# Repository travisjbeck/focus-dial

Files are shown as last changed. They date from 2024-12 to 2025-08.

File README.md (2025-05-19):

## The Story

I noticed that I am most productive when I set a timer to complete a task. This became even more apparent as I was learning to type again as there were drastically diminishing returns on learning after 25 minutes or so. 

So, I started looking for a "nice" timer to use. The nicer the better. I love beautiful objects and it seems like a super purposeful item like this is ripe for badass design and function. My initial search on amazon surfaced some decent cheap basic cheap options, and some very odd dated looking "pomodoro" specific timers. Nothing like I was looking for. I was looking for the "Peak Design" version of a workspace timer. Then, I found an indie gogo for exactly what I was looking for.   It had been funded in 48 hours and featured in Time Magazine, had tons of press, but sadly, they never shipped. Reading the company posts on indiegogo over time it became apparent these guys had a good idea, but no idea what they were doing. Even the product, upon closer inspection had some major flaws.  

Searching on, I came across a youtuber that was an original backer of the "Chi Timer" and wanted to see if he could just recreate it with readily available components and a 3D printer. He built something better in some ways, but lacking in others. He put the whole project on GitHub and created an instructable to walk people through building their own "Focus Timer". That video has been out 4 weeks and has 200,000 views. 

### The Spark

  It seems like there are a whole bunch of folks like me willing to shell out top dollar or spend many hours tinkering in order to have this product on their desks.  I get it.Its special. Its a beautiflu obnect that turns a mundane task into a ritual. rituals are powerful habit builders. People understand this. The best part is the mac and ios "Focus Mode" integrations as well as the unlimited integration potential of a custom webhook. 

  Let me see if I can build this and understand how it works. I want one, first of all, second of all, with some iteration this could be a commercially viable gadget that lots of people have already validated. I know this world. I know lots of people to make this happen. I've done it before and made a shit ton of invaluable mistakes that I don't have to make again. The intersection of software and hardware and design is the strongest gravitational pull I've ever felt in an idea. The challenge is real, and that's exciting. 

### The Expansion

Tariffs! Right, times have changed. Do I even want to make it in China? it's cheaper and easier, but is it exciting, does it help create the future I want? No.  We used to make things here. Great things. And thats important. Meaningful work and cratfmanship are important. The few proud people of America that get to work on meaningful, well-craftedh made-in-america things, be it jeans or pianos, they work hard and their work gives them meaning because they are working for something bigger than themselves or even the product. Can we make simple electronics in a plastic / wood / metal shell in America? of course. we can just do things. Ahh, but how much will it cost?  As much as it costs. Add the margin you need and sell it for top dollar. Just make sure as hell you deliver a "top-dollar" experience. Apple's not cornered the market on this making of beautiful objects and selling them for top dollar? Anyone can do that if they execute with the correct vision. I also think that just even "trying" to do this would win millions in free medea exposure. The timing is ripe. The mission becomes larger than the company or product.

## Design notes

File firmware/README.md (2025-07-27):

# Timer Arduino - Smooth Scrolling Demo

This is a high-performance smooth scrolling demo with three black screens for the ESP32-S3-Touch-AMOLED-1.75 device.

## Features
- Three scrollable screens with centered text
- Smooth horizontal scrolling with swipe gestures
- 16-bit RGB565 color (no color conversion)
- Optimized for 466x466 AMOLED display

## Hardware
- ESP32-S3-Touch-AMOLED-1.75 (WaveShare)
- QSPI display interface
- Capacitive touch

## Setup Instructions

1. **Copy Libraries**
   ```bash
   # From this directory, copy the required libraries:
   cp -r ../AMOLEDEXAMPLES/Arduino-v3.1.0/libraries/* ./libraries/
   ```

2. **Open in Arduino IDE**
   - Open `TheTimerArduino.ino` in Arduino IDE
   - Select Board: ESP32-S3 Dev Module
   - Select Port: /dev/cu.usbmodem2101 (or your device port)

3. **Configure Arduino IDE**
   - Board Settings:
     - Flash Size: 4MB
     - Partition Scheme: Default 4MB with spiffs
     - PSRAM: OPI PSRAM
     - Flash Mode: QIO 80MHz

4. **Upload**
   - Click Upload button in Arduino IDE
   - The device will show three scrollable black screens with text

## Troubleshooting
- If libraries are not found, ensure you've copied them from the AMOLEDEXAMPLES folder
- If touch doesn't work, check the I2C connections (SDA:15, SCL:14)
- If display doesn't work, verify QSPI connections match pin_config.h

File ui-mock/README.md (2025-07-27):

# Muji Japanese Minimal Timer UI - 466x466 Round Display

A minimalist timer interface inspired by Japanese design philosophy and Muji's aesthetic principles. Features warm, natural tones and embraces Ma (negative space).

## Design Principles

### Japanese Minimalism
- **Ma (間)**: Generous negative space throughout
- **Kanso (簡素)**: Essential elements only - no decorative buttons
- **Wabi-Sabi (侘寂)**: Natural, warm imperfections over sterile perfection

### Interface Design
- **No buttons**: Pure touch interaction, no pause/stop/start controls
- **Single accent color**: Muted sage green (#c2e189) throughout
- **Typography-focused**: Light weights with natural spacing
- **Automatic theme switching**: Demonstrates both modes seamlessly

## Structure

- `index.html` - Four screen layouts with Japanese minimal aesthetic
- `css/styles.css` - Warm, natural color palette with AMOLED-optimized dark mode
- `theme_info.md` - Detailed explanation of Japanese design philosophy
- Each display is 466x466px with circular boundary

## Color Palette

### Light Mode - Natural Paper Tones
```css
var(--light-bg-primary)     /* #FAFAF8 - Warm off-white */
var(--light-bg-secondary)   /* #F5F4F0 - Subtle warm gray */
var(--light-text-primary)   /* #57544F - Deep charcoal */
var(--light-text-secondary) /* #A8A5A0 - Soft warm gray */
var(--light-accent)         /* #c2e189 - Muted sage green */
var(--light-border)         /* #E8E6E1 - Subtle warm border */
```

### Dark Mode - AMOLED Optimized
```css
var(--dark-bg-primary)      /* #000000 - Pure black */
var(--dark-bg-secondary)    /* #0A0A0A - Near black */
var(--dark-text-primary)    /* #F5F4F0 - Warm off-white */
var(--dark-text-secondary)  /* #B8B5B0 - Muted warm gray */
var(--dark-accent)          /* #c2e189 - Same sage green */
var(--dark-border)          /* #1A1A1A - Subtle border */
```

## Screen Designs

### 1. Idle Screen
- **Central time display** (14:32) with ultra-light typography
- **Subtle status message** "No active timers"
- **Maximum Ma (negative space)** for peaceful rest state

### 2. Project Selection  
- **Clean vertical list** with perfect rhythm
- **Active selection** highlighted with sage green accent
- **Natural spacing** between project names

### 3. Timer Running
- **Large countdown display** as hero element
- **Minimal progress ring** (single pixel stroke)
- **Small project context** label above

### 4. Duration Selection
- **Prominent time selection** display
- **Text-only preset buttons** in horizontal layout
- **Active state** shown through color and subtle underline

## Typography Hierarchy

### Weight-Based Hierarchy
- **Ultra-light (200)**: Large time displays for maximum readability
- **Light (300)**: Body text and supporting information
- **Regular (400)**: Active states and emphasis only

### Size Scale
- **72px-96px**: Primary time displays
- **16px-18px**: Comfortable body text
- **14px**: Supporting labels and context

## Implementation Features

- **No interactive buttons**: Embraces pure touch/rotary navigation
- **Automatic theme demonstration**: Switches every 5 seconds
- **Responsive scaling**: Maintains proportions across screen sizes
- **AMOLED optimization**: Pure black backgrounds in dark mode
- **Natural transitions**: Soft, organic animation timing

## Design Philosophy

See `theme_info.md` for detailed explanation of Japanese design principles including Ma (negative space), Wabi-Sabi (imperfect beauty), and Kanso (simplicity).

## File Structure

```
ui_samples_v3_2/
├── index.html          # Four screen implementations
├── css/
│   └── styles.css      # Japanese minimal theme styles
├── theme_info.md       # Design philosophy documentation
└── README.md           # This file
```

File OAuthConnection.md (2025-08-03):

# thetimer.app OAuth Integration Implementation Guide

## Overview

This document outlines the implementation of OAuth-style authentication between the Timer Device and thetimer.app, allowing seamless connection without manual API key entry.

## Architecture

### Components

1. **Timer Device (Client)**
   - Web interface at `http://thetimer.local`
   - Runs on ESP32-S3 with web server
   - Stores API credentials in NVS

2. **thetimer.app (Server)**
   - Next.js application
   - Handles user authentication
   - Generates device-specific API keys

### Authentication Flow

```
Timer Device                    thetimer.app                    User
     |                              |                             |
     |--- 1. Click "Connect" ------>|                             |
     |                              |                             |
     |<-- 2. Open popup window -----|                             |
     |    (to /device-auth)         |                             |
     |                              |<---- 3. User logs in -------|
     |                              |                             |
     |                              |---- 4. Generate API key --->|
     |                              |                             |
     |<-- 5. postMessage with ------|                             |
     |    credentials               |                             |
     |                              |                             |
     |--- 6. Save credentials ----->|                             |
     |                              |                             |
     |<-- 7. Confirm connection ----|                             |
```

## Implementation Details

### Timer Device Side (Web Interface)

#### 1. Update UI in `firmware/data/index.html`

Replace the current webhook configuration section with:

```html
<section class="card" id="integration-section">
  <div class="card-header">
    <h2>
      <i data-lucide="cloud" class="icon"></i>
      thetimer.app Integration
    </h2>
  </div>
  <div class="form-content">
    <!-- Not Connected State -->
    <div id="not-connected" class="connection-state">
      <div class="integration-info">
        <p>Connect to thetimer.app to:</p>
        <ul>
          <li>Sync your timer data to the cloud</li>
          <li>Access detailed analytics and reports</li>
          <li>Share projects with your team</li>
          <li>7-day free trial, then subscription required</li>
        </ul>
      </div>
      <button type="button" class="btn primary-btn" id="connect-button">
        <i data-lucide="link" class="icon"></i>
        <span>Connect to thetimer.app</span>
      </button>
    </div>
    
    <!-- Connected State -->
    <div id="connected" class="connection-state" style="display: none;">
      <div class="connection-status">
        
        <div class="status-info">
          <p class="status-text">Connected to thetimer.app</p>
          
          <p class="last-sync">Last synced: <span id="last-sync-time">Never</span></p>
        </div>
      </div>
      <button type="button" class="btn secondary-btn danger-btn" id="disconnect-button">
        <i data-lucide="unlink" class="icon"></i>
        <span>Disconnect</span>
      </button>
    </div>
  </div>
</section>
```

#### 2. JavaScript OAuth Handler in `firmware/data/app.js`

```javascript
// OAuth Configuration
const TIMER_APP_URL = 'https://thetimer.app';
const DEVICE_AUTH_ENDPOINT = '/device-auth';
const WEBHOOK_ENDPOINT = '/api/webhook';

let authWindow = null;

// Initialize connection state
async function initializeIntegration() {
  const apiKey = await fetchStoredApiKey();
  updateConnectionUI(!!apiKey);
  
  if (apiKey) {
    // Verify connection is still valid
    verifyConnection(apiKey);
  }
}

// Handle Connect button click
document.getElementById('connect-button').addEventListener('click', async () => {
  // Generate state parameter for security
  const state = generateRandomState();
  sessionStorage.setItem('oauth_state', state);
  
  // Get device information
  const deviceInfo = await getDeviceInfo();
  
  // Build OAuth URL
  const authUrl = new URL(DEVICE_AUTH_ENDPOINT, TIMER_APP_URL);
  authUrl.searchParams.append('device_id', deviceInfo.id);
  authUrl.searchParams.append('device_name', deviceInfo.name);
  authUrl.searchParams.append('state', state);
  authUrl.searchParams.append('callback_origin', window.location.origin);
  
  // Open popup window
  const width = 600;
  const height = 700;
  const left = (window.screen.width - width) / 2;
  const top = (window.screen.height - height) / 2;
  
  authWindow = window.open(
    authUrl.toString(),
    'TimerAppAuth',
    `width=${width},height=${height},left=${left},top=${top},toolbar=no,menubar=no`
  );
  
  // Start listening for response
  window.addEventListener('message', handleAuthMessage);
});

// Handle postMessage from thetimer.app
async function handleAuthMessage(event) {
  // Verify origin
  if (event.origin !== TIMER_APP_URL) return;
  
  // Verify state
  const savedState = sessionStorage.getItem('oauth_state');
  if (!savedState || event.data.state !== savedState) {
    console.error('Invalid state parameter');
    return;
  }
  
  // Extract credentials
  const { api_key, account_email, webhook_url } = event.data;
  
  if (api_key) {
    // Save credentials
    await saveCredentials({
      api_key,
      webhook_url: webhook_url || `${TIMER_APP_URL}${WEBHOOK_ENDPOINT}`,
      account_email
    });
    
    // Update UI
    updateConnectionUI(true, account_email);
    
    // Close popup
    if (authWindow) {
      authWindow.close();
    }
    
    // Clean up
    sessionStorage.removeItem('oauth_state');
    window.removeEventListener('message', handleAuthMessage);
    
    showMessage('Successfully connected to thetimer.app!', 'success');
  }
}

// Save credentials to device
async function saveCredentials(credentials) {
  const response = await fetch('/api/webhook', {
    method: 'POST',
    headers: { 'Content-Type': 'application/json' },
    body: JSON.stringify({
      webhook_url: credentials.webhook_url,
      api_key: credentials.api_key
    })
  });
  
  if (!response.ok) {
    throw new Error('Failed to save credentials');
  }
  
  // Store additional metadata locally
  localStorage.setItem('timer_app_email', credentials.account_email);
  localStorage.setItem('timer_app_connected_at', new Date().toISOString());
}

// Handle disconnect
document.getElementById('disconnect-button').addEventListener('click', async () => {
  if (confirm('Are you sure you want to disconnect from thetimer.app?')) {
    await fetch('/api/webhook', {
      method: 'POST',
      headers: { 'Content-Type': 'application/json' },
      body: JSON.stringify({
        webhook_url: '',
        api_key: ''
      })
    });
    
    localStorage.removeItem('timer_app_email');
    localStorage.removeItem('timer_app_connected_at');
    
    updateConnectionUI(false);
    showMessage('Disconnected from thetimer.app', 'success');
  }
});

// Utility functions
function generateRandomState() {
  return Array.from(crypto.getRandomValues(new Uint8Array(16)))
    .map(b => b.toString(16).padStart(2, '0'))
    .join('');
}

async function getDeviceInfo() {
  // Get device MAC address as unique ID
  const response = await fetch('/api/system/info');
  const info = await response.json();
  
  return {
    id: info.mac_address || 'unknown',
    name: info.hostname || 'Timer Device'
  };
}

function updateConnectionUI(isConnected, email = null) {
  const notConnected = document.getElementById('not-connected');
  const connected = document.getElementById('connected');
  
  if (isConnected) {
    notConnected.style.display = 'none';
    connected.style.display = 'block';
    
    if (email) {
      document.getElementById('account-email').textContent = email;
    } else {
      const savedEmail = localStorage.getItem('timer_app_email');
      if (savedEmail) {
        document.getElementById('account-email').textContent = savedEmail;
      }
    }
    
    // Update last sync time
    updateLastSyncTime();
  } else {
    notConnected.style.display = 'block';
    connected.style.display = 'none';
  }
}
```

### thetimer.app Side (Next.js)

#### 1. Device Authentication Page (`pages/device-auth.tsx`)

```typescript
import { useEffect, useState } from 'react';
import { useRouter } from 'next/router';
import { useSession } from 'next-auth/react';

export default function DeviceAuth() {
  const router = useRouter();
  const { data: session, status } = useSession();
  const [isProcessing, setIsProcessing] = useState(false);
  
  const { device_id, device_name, state, callback_origin } = router.query;

  useEffect(() => {
    // Redirect to login if not authenticated
    if (status === 'unauthenticated') {
      router.push(`/auth/signin?callbackUrl=${encodeURIComponent(router.asPath)}`);
    }
  }, [status, router]);

  useEffect(() => {
    // Process authentication once logged in
    if (session && device_id && state && callback_origin && !isProcessing) {
      handleDeviceAuth();
    }
  }, [session, device_id, state, callback_origin]);

  const handleDeviceAuth = async () => {
    setIsProcessing(true);
    
    try {
      // Create or retrieve API key for this device
      const response = await fetch('/api/devices/authenticate', {
        method: 'POST',
        headers: { 'Content-Type': 'application/json' },
        body: JSON.stringify({
          device_id,
          device_name,
          user_id: session.user.id
        })
      });
      
      const data = await response.json();
      
      if (data.api_key) {
        // Send credentials back to device
        window.opener.postMessage({
          api_key: data.api_key,
          webhook_url: `${process.env.NEXT_PUBLIC_APP_URL}/api/webhook`,
          account_email: session.user.email,
          state
        }, callback_origin as string);
        
        // Show success and close window
        setTimeout(() => {
          window.close();
        }, 1000);
      }
    } catch (error) {
      console.error('Device authentication failed:', error);
      // Show error to user
    }
  };

  return (
    <div className="min-h-screen flex items-center justify-center">
      <div className="max-w-md w-full space-y-8 p-8">
        <div className="text-center">
          <h2 className="text-3xl font-bold">Connect Your Timer Device</h2>
          {session ? (
            <>
              <p className="mt-2 text-gray-600">
                Connecting device to your account: {session.user.email}
              </p>
              <div className="mt-4">
                
              </div>
            </>
          ) : (
            <p className="mt-2 text-gray-600">
              Please log in to connect your device
            </p>
          )}
        </div>
      </div>
    </div>
  );
}
```

#### 2. API Endpoint (`pages/api/devices/authenticate.ts`)

```typescript
import { NextApiRequest, NextApiResponse } from 'next';
import { getSession } from 'next-auth/react';
import { prisma } from '@/lib/prisma';
import { generateApiKey } from '@/lib/auth';

export default async function handler(req: NextApiRequest, res: NextApiResponse) {
  if (req.method !== 'POST') {
    return res.status(405).json({ error: 'Method not allowed' });
  }

  const session = await getSession({ req });
  if (!session) {
    return res.status(401).json({ error: 'Unauthorized' });
  }

  const { device_id, device_name } = req.body;

  try {
    // Check if device already exists
    let device = await prisma.device.findUnique({
      where: { device_id }
    });

    if (device && device.user_id !== session.user.id) {
      return res.status(403).json({ error: 'Device registered to another user' });
    }

    // Generate new API key
    const api_key = generateApiKey();

    if (device) {
      // Update existing device
      device = await prisma.device.update({
        where: { device_id },
        data: {
          api_key,
          last_connected: new Date()
        }
      });
    } else {
      // Create new device
      device = await prisma.device.create({
        data: {
          device_id,
          device_name,
          api_key,
          user_id: session.user.id,
          trial_ends_at: new Date(Date.now() + 7 * 24 * 60 * 60 * 1000) // 7 days
        }
      });
    }

    return res.status(200).json({
      api_key,
      device_id: device.device_id
    });
  } catch (error) {
    console.error('Device authentication error:', error);
    return res.status(500).json({ error: 'Internal server error' });
  }
}
```

## Security Considerations

1. **State Parameter**: Prevents CSRF attacks
2. **Origin Verification**: Only accept postMessage from thetimer.app
3. **HTTPS Required**: All communication over secure channels
4. **API Key Rotation**: Implement key rotation mechanism
5. **Device Binding**: API keys tied to specific device IDs

## Implementation Checklist

### Timer Device
- [ ] Update HTML with new integration UI
- [ ] Implement OAuth JavaScript handler
- [ ] Add connection state management
- [ ] Update CSS for connection status indicators
- [ ] Test popup window communication
- [ ] Handle error states gracefully

### thetimer.app
- [ ] Create device authentication page
- [ ] Implement device registration API
- [ ] Add device management to user dashboard
- [ ] Set up trial/subscription validation
- [ ] Configure CORS for device communication
- [ ] Test postMessage flow

## Testing

1. **Happy Path**
   - User clicks connect
   - Logs in successfully
   - Device receives credentials
   - Connection status updates

2. **Error Cases**
   - User closes popup without authenticating
   - Network failure during authentication
   - Invalid credentials
   - Expired trial

3. **Security**
   - Verify state parameter validation
   - Test origin verification
   - Ensure API keys are stored securely

## Future Enhancements

1. **Device Management Dashboard**: Allow users to see all connected devices
2. **Automatic Reconnection**: Handle token refresh
3. **Offline Queue**: Store timer data locally when disconnected
4. **Multi-device Sync**: Sync projects across devices
5. **Push Notifications**: Real-time updates to devices

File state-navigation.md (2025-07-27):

# Timer State Machine Navigation

## State Diagram

```
┌─────────────────┐
│   StartupState  │ (2 sec splash)
└────────┬────────┘
         │
         ▼
┌─────────────────┐
│ ProvisionState  │ (First run only - WiFi setup)
└────────┬────────┘
         │ WiFi configured
         ▼
┌─────────────────┐ Rotate Encoder  ┌─────────────────┐
│                 │ ───────────────> │                 │
│   IdleState     │                  │  AdjustState    │
│   (25:00)       │ <─────────────── │ (Timer Duration)│
│                 │    Tap Screen    │                 │
└────────┬────────┘                  └─────────────────┘
         │ Tap Screen
         ▼
┌─────────────────┐
│ProjectSelectState│ 
│ (Choose Project) │
└────────┬────────┘
         │ Tap Screen (Start Timer)
         ▼
┌─────────────────┐ Tap Screen      ┌─────────────────┐
│                 │ ───────────────> │                 │
│   TimerState    │                  │  PausedState    │
│   (Running)     │ <─────────────── │   (Paused)      │
│                 │    Tap Screen    │                 │
└────────┬────────┘                  └────────┬────────┘
         │ Long Press                         │ Long Press
         ▼                                    ▼
┌─────────────────┐
│   DoneState     │
│  (Completed)    │
└────────┬────────┘
         │ Tap Screen
         ▼
    [Back to IdleState]
```

## Input Summary

### Rotary Encoder
- **IdleState**: Rotate to enter AdjustState (timer duration)
- **AdjustState**: Rotate to change timer duration (5-240 min)
- **ProjectSelectState**: Rotate to scroll through projects

### Screen Tap
- **IdleState**: Tap to enter ProjectSelectState
- **AdjustState**: Tap to save duration and return to IdleState
- **ProjectSelectState**: Tap to select project and start timer
- **TimerState**: Tap to pause
- **PausedState**: Tap to resume
- **DoneState**: Tap to return to IdleState

### Long Press
- **TimerState**: Long press to end timer early
- **PausedState**: Long press to end timer early

### Power Button (Hardware)
- **Any State**: Press to enter deep sleep
- **Deep Sleep**: Press BOOT button to wake

### Inactivity
- **IdleState**: 3 minutes → Light sleep (touch to wake)
- **Other States**: No timeout during active use

## Key Behaviors

1. **WiFi Check**: On every boot, check if WiFi is configured. Skip ProvisionState if already set up.

2. **Timer Modes**: Timer can count up or down (need to clarify which mode is used when).

3. **Project Colors**: Each project has an associated color that affects:
   - LED ring color during timer
   - UI accent colors
   - Progress indicators

4. **State Persistence**: 
   - Timer duration saved between sessions
   - Current project remembered
   - WiFi credentials stored in NVS

5. **Simplified Input**: Everything is either:
   - Single tap (most common - state transitions)
   - Long press (only in timer/paused states to end timer)
   - Encoder rotation (value adjustments)

## Implementation Notes

1. **Touch Debouncing**: Already implemented in TheTimerArduino
2. **State Transition Animation**: Fade transitions already working
3. **Encoder Interrupts**: Need to implement on GPIO 17/18
4. **Long Press Detection**: Need to add to LVGL event handling
5. **WiFi Check**: Need to port from old firmware's NetworkController

## Testing Each Transition

1. Boot → Provision → Idle (first run)
2. Boot → Idle (subsequent runs)
3. Idle ↔ Adjust (encoder/tap cycle)
4. Idle → Project → Timer (tap flow)
5. Timer ↔ Paused (tap toggle)
6. Timer/Paused → Done (long press)
7. Done → Idle (tap)
8. Any → Sleep → Wake (power/inactivity)

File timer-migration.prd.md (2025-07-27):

# Timer Migration PRD - ESP32-S3-Touch-AMOLED-1.75

## Executive Summary

This document outlines the product requirements for migrating an existing timer application from ESP32 XIAO hardware with OLED display to the new ESP32-S3-Touch-AMOLED-1.75 hardware. The migration will preserve all existing functionality while leveraging the new hardware's superior display capabilities, touch interface, and power management features.

**Core Development Philosophy: Test Constantly, Build Consistently, Iterate in Small Chunks**

## Development Methodology

### Continuous Testing & Iteration

1. **Micro-Iterations**
   - Each feature implemented in small chunks
   - Compile and test after EVERY code change
   - Never accumulate untested changes
   - Roll back immediately if build fails

2. **Build-First Approach**
   ```bash
   # Standard build & test cycle (run after EVERY change)
   cd /Users/Travis/Developer/waveshare_hardware_test/TheTimerArduino && \
   arduino-cli compile --fqbn esp32:esp32:esp32s3:USBMode=hwcdc --build-property "build.psram_type=opi" && \
   arduino-cli upload -p /dev/cu.usbmodem32301 --fqbn esp32:esp32:esp32s3:USBMode=hwcdc && \
   sleep 2 && \
   esptool.py --port /dev/cu.usbmodem32301 read_mac >/dev/null 2>&1 && \
   sleep 0.5 && \
   timeout 30 cat /dev/cu.usbmodem32301
   ```

3. **Error-First Development**
   - Expect errors and plan for them
   - Add serial debugging before functionality
   - Test edge cases before happy path
   - Document every error and solution

4. **Incremental Feature Addition**
   - Start with minimal viable feature
   - Test thoroughly
   - Add one small enhancement
   - Test again
   - Repeat

## Hardware Specifications

### New Hardware: ESP32-S3-Touch-AMOLED-1.75
- **Display**: 466x466 AMOLED with 16-bit RGB565 color
- **Touch**: Capacitive touch screen (CSTXXX driver)
- **MCU**: ESP32-S3 with 8MB PSRAM
- **Interface**: QSPI (4-wire SPI) for display
- **Power**: AXP2101 PMU with battery management
- **RTC**: Built-in real-time clock controller
- **Connectivity**: WiFi, Bluetooth
- **Expansion**: TCA9554 IO expander for additional GPIO

### Peripheral Connections

#### Breakout Board Header (8-pin)
The ESP32-S3-Touch-AMOLED-1.75 provides an 8-pin header with:
- **IO18**: GPIO18
- **IO17**: GPIO17  
- **IO16**: GPIO16
- **RXD**: UART RX (can be used as GPIO)
- **TXD**: UART TX (can be used as GPIO)
- **3V3**: 3.3V power supply
- **GND**: Ground
- **VBUS**: 5V from USB

#### Rotary Encoder Connections
- **Encoder A**: IO17 (GPIO17)
- **Encoder B**: IO18 (GPIO18)
- **Encoder Common**: GND
- **Note**: The old firmware used GPIO43/8. Code will need to be updated for GPIO17/18.

#### NeoPixel LED Ring Connections
- **Data Pin**: IO16 (GPIO16)
- **Power**: 3V3 (for consistent 3.3V operation)
- **Ground**: GND
- **LED Count**: 24 LEDs (upgraded from 16)
- **Type**: NEO_GRB + NEO_KHZ800
- **Note**: Using 3.3V ensures consistent brightness whether on USB or battery power.

### Testing Points for Hardware
1. **GPIO Availability Test**: Verify each pin works before wiring
2. **Voltage Test**: Confirm 3.3V on all peripherals
3. **Current Draw Test**: Measure with all LEDs on
4. **Signal Integrity Test**: Check encoder pulses with scope

## Current Implementation Status

### Already Completed in TheTimerArduino
- ✅ Display initialized (466x466 AMOLED with Arduino_CO5300)
- ✅ Touch input working (CSTXXX driver)
- ✅ LVGL configured with proper buffers
- ✅ First UI screen complete (idle timer display)
- ✅ Custom fonts loaded (Roboto Mono 120pt, Barlow 24pt)
- ✅ Screen transitions with fade animation
- ✅ Tap navigation between screens
- ✅ Inactivity timeout (3 minutes → light sleep)
- ✅ Power button → deep sleep
- ✅ BOOT button → wake from deep sleep
- ✅ Touch wake from light sleep

### Hardware Setup
- **Physical Rotary Encoder**: Will connect to GPIO 17/18
- **NeoPixel LED Ring**: Will connect to GPIO 16
- **Touch Input**: Replaces all button functions with simple tap

## Migration Strategy

### Key Differences from Original Plan
1. **Physical Encoder Retained**: No virtual dial needed - using real rotary encoder
2. **Simplified Touch**: Primarily single tap, with long-press only in timer states to end timer
3. **Starting Point**: Display, touch, and sleep already working in TheTimerArduino
4. **UI Foundation**: First screen (idle timer) already implemented with custom fonts

### Input Mapping
- **Screen Tap** = Old button click (context-sensitive per state)
- **Long Press** = End timer early (only in TimerState and PausedState)
- **Encoder Rotation** = Value adjustment (unchanged)
- **Power Button** = Deep sleep (already implemented)
- **Touch Wake** = Wake from light sleep (already implemented)

### State Machine Navigation Flow

**Initial Boot**:
1. **StartupState** (2 seconds splash) → 
2. **ProvisionState** (if no WiFi configured) → Enter WiFi credentials
3. Skip to **IdleState** if WiFi already configured

**From IdleState** (main screen showing 25:00):
- **Rotate Encoder** → **AdjustState** (timer duration setting)
- **Tap Screen** → **ProjectSelectState**

**From AdjustState** (timer duration setting):
- **Rotate Encoder** → Adjust timer duration (5-240 minutes)
- **Tap Screen** → Save duration and return to **IdleState**

**From ProjectSelectState**:
- **Rotate Encoder** → Scroll through projects
- **Tap Screen** → Start timer → **TimerState**

**From TimerState** (timer running):
- **Tap Screen** → **PausedState**
- **Long Press** → End timer → **DoneState**

**From PausedState**:
- **Tap Screen** → Resume → **TimerState**
- **Long Press** → End timer → **DoneState**

**From DoneState**:
- **Tap Screen** → Return to **IdleState**

## Core Features to Migrate

### Implementation Order (Test-Driven)

#### Phase 1: State Machine Integration
**Port State Machine Framework**
- [ ] Copy state machine files from old firmware
- [ ] Update CMakeLists.txt / includes
- [ ] Create empty state implementations
- [ ] Test state transitions work
- [ ] Connect screen tap to state changes

**Integrate with Existing UI**
- [ ] Connect idle screen to IdleState
- [ ] Update timer display from state
- [ ] Test tap starts/stops timer
- [ ] Verify state persistence

#### Phase 2: Hardware Peripherals
**Physical Encoder Integration**
- [ ] Wire encoder to GPIO 17/18
- [ ] Test encoder rotation detection
- [ ] Port InputController with new pins
- [ ] Test value adjustment in AdjustState
- [ ] Verify interrupt handling works

**NeoPixel LED Ring**
- [ ] Wire LEDs to GPIO 16 with 3.3V power
- [ ] Test single LED at 3.3V
- [ ] Port LEDController to new pin
- [ ] Test all animation patterns
- [ ] Verify brightness levels adequate

#### Phase 3: State Implementation
**Core States**
- [ ] IdleState (with all tests)
- [ ] AdjustState (with all tests)
- [ ] TimerState (with all tests)
- [ ] ProjectSelectState (with all tests)
- [ ] PausedState & DoneState
- [ ] SleepState & power management
- [ ] Integration testing

#### Phase 4: Network Features
**WiFi Provisioning**
- [ ] Test 1: AP mode starts
- [ ] Test 2: Can connect to AP
- [ ] Test 3: Provisioning saves credentials
- [ ] Feature: WiFi provisioning works

**Web Server**
- [ ] Test 1: Server starts
- [ ] Test 2: Index page loads
- [ ] Test 3: API responds
- [ ] Feature: Basic web interface

**Project Management**
- [ ] Test 1: Create project via API
- [ ] Test 2: List projects
- [ ] Test 3: Delete project
- [ ] Test 4: Projects persist
- [ ] Feature: Full project CRUD

### Testing Infrastructure

#### Serial Debug Framework
```cpp
// Add to every state enter()
USBSerial.println("=== ENTERING STATE: StateName ===");
USBSerial.print("Free heap: ");
USBSerial.println(ESP.getFreeHeap());
USBSerial.print("Timestamp: ");
USBSerial.println(millis());

// Add to every state exit()
USBSerial.println("=== EXITING STATE: StateName ===");
```

#### Memory Monitoring
```cpp
// Run every 10 seconds in loop()
static unsigned long lastMemCheck = 0;
if (millis() - lastMemCheck > 10000) {
    USBSerial.print("HEAP: ");
    USBSerial.print(ESP.getFreeHeap());
    USBSerial.print(" PSRAM: ");
    USBSerial.println(ESP.getFreePsram());
    lastMemCheck = millis();
}
```

#### Crash Recovery
```cpp
// Add to setup()
esp_reset_reason_t reset_reason = esp_reset_reason();
USBSerial.print("Reset reason: ");
USBSerial.println(reset_reason);
if (reset_reason == ESP_RST_PANIC) {
    USBSerial.println("RECOVERED FROM CRASH!");
    // Log crash context if available
}
```

### Error Handling Strategy

1. **Never Silent Fail**
   - Every function returns success/failure
   - Every failure logs detailed error
   - Every error has recovery path

2. **Defensive Programming**
   ```cpp
   // Example pattern for all functions
   bool initializeComponent() {
       USBSerial.println("Initializing component X...");
       
       if (!component.begin()) {
           USBSerial.println("ERROR: Component X failed to initialize");
           USBSerial.println("Attempting recovery...");
           delay(100);
           if (!component.begin()) {
               USBSerial.println("FATAL: Component X unrecoverable");
               return false;
           }
       }
       
       USBSerial.println("Component X initialized successfully");
       return true;
   }
   ```

3. **Test Harness Mode**
   ```cpp
   // Add compile flag for test mode
   #ifdef TEST_MODE
   void runTestSuite() {
       testDisplay();
       testTouch();
       testEncoder();
       testLEDs();
       testStates();
       testMemory();
       reportResults();
   }
   #endif
   ```

## UI/UX Requirements

### Iterative UI Development

1. **Phase 1: Boxes and Text**
   - Just get text on screen
   - Verify positioning
   - Test touch zones

2. **Phase 2: Fonts and Sizes**
   - Add custom fonts one at a time
   - Test memory impact
   - Verify readability

3. **Phase 3: Colors and Polish**
   - Add colors incrementally
   - Test brightness levels
   - Verify power consumption

4. **Phase 4: Animations**
   - Start with simple fades
   - Test performance impact
   - Add complexity gradually

### Screen Layouts (Based on TheTimerUI.png)

#### Testing Each Screen
1. **Create static mockup first**
2. **Test touch zones with colored boxes**
3. **Add real content**
4. **Test state persistence**
5. **Test transitions in/out**

## Technical Requirements

### Build Configuration
```bash
# Always use these exact flags
--fqbn esp32:esp32:esp32s3:USBMode=hwcdc
--build-property "build.psram_type=opi"
```

### Critical Testing Points

1. **Display Buffer Allocation**
   - Test with small buffer first
   - Increase size gradually
   - Monitor free memory
   - Find optimal size

2. **Touch Calibration**
   - Log raw coordinates
   - Test all four corners
   - Verify center point
   - Check edge detection

3. **Power Management**
   - Test wake sources individually
   - Measure current in each state
   - Verify sleep entry/exit
   - Test battery life

## Continuous Integration

### Testing Checklist
- [ ] Each feature: Build and upload
- [ ] After implementation: Test all states
- [ ] Regular intervals: Memory leak check
- [ ] Each error: Document and fix immediately

### Error Log Template
```
Error: [Description]
Context: [What was being tested]
Serial Output: [Paste output]
Solution: [How it was fixed]
Prevention: [How to avoid in future]
```

## Acceptance Criteria

### Incremental Acceptance
Each feature must pass these gates:

1. **Gate 1: Builds without warnings**
2. **Gate 2: Uploads successfully**
3. **Gate 3: Runs for 1 minute without crash**
4. **Gate 4: Survives 10 state transitions**
5. **Gate 5: Works after power cycle**
6. **Gate 6: Memory usage stable**

### Feature-Specific Tests
Document specific test cases for each feature BEFORE implementing.

## Risk Mitigation

### Common Pitfalls & Solutions

1. **Memory Fragmentation**
   - Test: Long-running state transitions
   - Solution: Pre-allocate all buffers
   - Prevention: No dynamic allocation in loop()

2. **I2C Conflicts**
   - Test: Access all I2C devices sequentially
   - Solution: Add mutexes if needed
   - Prevention: Single I2C manager class

3. **Display Corruption**
   - Test: Rapid screen switches
   - Solution: Proper LVGL mutex usage
   - Prevention: Single display update point

4. **Touch Glitches**
   - Test: Rapid touch events
   - Solution: Debouncing and rate limiting
   - Prevention: State-based touch handling

## Development Tools

### Essential Debugging Commands
```bash
# Monitor with timestamp
arduino-cli monitor -p /dev/cu.usbmodem32301 --timestamp

# Quick reset and monitor
esptool.py --port /dev/cu.usbmodem32301 read_mac && sleep 0.5 && cat /dev/cu.usbmodem32301

# Flash and monitor in one command
./build_and_monitor.sh
```

### Performance Monitoring
```cpp
// Add to critical sections
unsigned long start = micros();
// ... code to measure ...
unsigned long duration = micros() - start;
if (duration > 1000) { // Log if > 1ms
    USBSerial.print("PERF WARNING: ");
    USBSerial.print(functionName);
    USBSerial.print(" took ");
    USBSerial.print(duration);
    USBSerial.println("us");
}
```

## Migration Challenges & Solutions

### 1. Physical Encoder Pin Changes
**Challenge**: Old pins GPIO 43/8 don't exist on new hardware
**Solution**: Remap to GPIO 17/18 on breakout header
```cpp
#define ENCODER_A_PIN 17  // Was 43
#define ENCODER_B_PIN 18  // Was 8
```

### 2. Long Press Detection
**Challenge**: Need long press for ending timer early
**Solution**: Add LVGL long press events
```cpp
lv_obj_add_event_cb(screen, long_press_cb, LV_EVENT_LONG_PRESSED, NULL);
lv_obj_add_event_cb(screen, long_press_repeat_cb, LV_EVENT_LONG_PRESSED_REPEAT, NULL);
```

### 3. NeoPixel 3.3V Operation
**Challenge**: LEDs designed for 5V, using 3.3V supply
**Solution**: 
- Test signal integrity first
- Reduce brightness if needed
- Most WS2812B work fine at 3.3V

### 4. Display Memory Requirements
**Challenge**: 466x466 display needs large buffers
**Solution**: Already using PSRAM in TheTimerArduino
```cpp
buf1 = (lv_color_t*)heap_caps_malloc(buffer_size * sizeof(lv_color_t), 
                                      MALLOC_CAP_DMA | MALLOC_CAP_SPIRAM);
```

### 5. Touch Wake Configuration
**Challenge**: Different wake source than physical button
**Solution**: Already implemented using GPIO11
```cpp
gpio_wakeup_enable(GPIO_NUM_11, GPIO_INTR_LOW_LEVEL);
esp_sleep_enable_gpio_wakeup();
```

### 6. State Machine Integration
**Challenge**: Connect existing UI to state logic
**Solution**: 
- Port state files from old firmware
- Map touch/encoder events to state handlers
- Preserve existing screen transition code

### 7. WiFi Provisioning Check
**Challenge**: Skip provisioning if already configured
**Solution**: Check NVS on boot
```cpp
if (!networkController.isWiFiProvisioned()) {
    stateMachine.changeState(&provisionState);
} else {
    stateMachine.changeState(&idleState);
}
```

### 8. Project Color Preview
**Challenge**: Show colors on both display and LEDs
**Solution**: Update display preview while keeping LED feedback

## Testing Strategy

### Hardware Test Order
1. Encoder on new pins (GPIO 17/18)
2. NeoPixels at 3.3V (GPIO 16)
3. Combined encoder + LED operation
4. State transitions with real hardware

### Debug Infrastructure
```cpp
#define DEBUG_MIGRATION 1
#if DEBUG_MIGRATION
  #define MIG_LOG(x) USBSerial.println(x)
#else
  #define MIG_LOG(x)
#endif
```

## Success Metrics

1. **Build Success Rate**: >95% (track daily)
2. **Crash-Free Runtime**: >4 hours continuous
3. **Memory Stability**: <5% variation over 1 hour
4. **Response Time**: <100ms for all interactions
5. **Code Coverage**: Test every state transition

## Appendix: Pin Assignments Summary

| Function | GPIO Pin | Header Pin | Notes |
|---|---|---|---|
| LED Data | GPIO16 | IO16 | NeoPixel data line |
| Encoder A | GPIO17 | IO17 | Rotary encoder channel A |
| Encoder B | GPIO18 | IO18 | Rotary encoder channel B |
| Power Button | PMU IRQ | Internal | Via AXP2101 |
| Wake Button | GPIO0 | Internal | BOOT button |
| Touch INT | GPIO11 | Internal | Touch interrupt |
| Display CS | GPIO12 | Internal | QSPI chip select |

### Wiring Diagram
```
ESP32-S3-Touch-AMOLED Breakout Header:
┌─────────────────────┐
│ VBUS  ○             │ 5V USB Power
│ GND   ○─────────┐   │ Common Ground
│ 3V3   ○───┐     │   │ 3.3V Power
│ TXD   ○   │     │   │ (Not used)
│ RXD   ○   │     │   │ (Not used)
│ IO16  ○───┼─────┼───│ → NeoPixel Data
│ IO17  ○───┼─────┼───│ → Encoder A
│ IO18  ○───┼─────┼───│ → Encoder B
└───────────┼─────┼───┘
            │     │
    ┌───────┴─────┴────┐
    │   NeoPixel Ring  │
    │   VCC ← 3V3      │
    │   GND ← GND      │
    │   DIN ← IO16     │
    └──────────────────┘
    
    ┌──────────────────┐
    │  Rotary Encoder  │
    │   A   ← IO17     │
    │   B   ← IO18     │
    │   COM ← GND      │
    └──────────────────┘
```

---

*Remember: Small changes, constant testing, immediate fixes. Never let errors accumulate.*

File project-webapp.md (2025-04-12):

# Focus Dial - Time Tracking Web Application Development Plan

## 1. Project Context & Goal

### Device Summary
- **Name:** Focus Dial
- **Purpose:** Firmware for the "Focus Dial" hardware.
- **Functionality:** A timer device with a rotary dial input, OLED display (128x64), and NeoPixel LED ring indicator. Allows setting timers with configurable intervals, associated with user-defined projects (name, color). Features Wi-Fi connectivity with webhook callback capabilities and a local web server for configuration.
- **Hardware:** Adafruit QT Py ESP32-S2 (240MHz Tensilica processor, 4MB Flash, 2MB PSRAM).

### Existing Firmware Features (Relevant)
- Timer functionality (start, stop, pause, resume, done).
- Project management via web UI (add, edit, delete projects with names and colors stored in NVS).
- Project selection on the device before starting a timer.
- Visual feedback using LED ring color based on selected project.
- Webhook calls triggered on timer actions (`start`, `stop`, `done`) including the selected project name (e.g., `start|ProjectName`).
- Configuration web UI served directly from the device via `ESPAsyncWebServer` and accessible via mDNS (`focus-dial.local`).

### Web Application Goal
Create a web application (React SPA) to act as a dashboard and time-tracking system. This application will receive webhook data from the Focus Dial, store time entries, allow users to manage/annotate these entries, and generate invoices based on project time.

## 2. Chosen Architecture

- **Backend/Database:** Run on a separate, dedicated machine (e.g., **Raspberry Pi**) using Node.js (Express) and a database (e.g., SQLite initially). **This avoids running complex server/database logic directly on the resource-constrained ESP32-S2.**
- **Frontend:** React Single Page Application (SPA), built and served statically by the backend server on the Raspberry Pi.
- **Communication:** The Focus Dial firmware will send webhook POST requests to an API endpoint hosted on the Raspberry Pi backend server.

## 3. Development Tasks (Raspberry Pi Backend / React Frontend)

### Phase 1: Backend Setup & API (Raspberry Pi)

- [ ] **Environment Setup:**
  - [ ] Set up Raspberry Pi with OS (e.g., Raspberry Pi OS).
  - [ ] Install Node.js and npm/yarn.
  - [ ] Choose and install a database (e.g., SQLite).
  - [ ] Set up a process manager (e.g., `pm2`).
- [ ] **Project Initialization:**
  - [ ] Create a new Node.js project directory.
  - [ ] Initialize `package.json`.
  - [ ] Install core dependencies: `express`, `sqlite3`, `cors`, potentially an ORM (`sequelize` or `prisma`).
- [ ] **Database Schema Design:**
  - [ ] Define tables: `projects` (id, name, color, created_at, updated_at), `time_entries` (id, project_id, start_time, end_time, duration_seconds, description, invoiced, created_at, updated_at), `invoices` (id, project_id, invoice_date, total_amount, status, created_at, updated_at), `invoice_items` (id, invoice_id, time_entry_id).
  - [ ] Set up database creation/migration scripts.
- [ ] **API Server Implementation (Express.js):**
  - [ ] Set up basic Express server structure (app setup, middleware like `cors`, `json` body parser).
  - [ ] Implement API routes/controllers:
    - [ ] `POST /api/webhook`: Receives `action`, `project_name` from Focus Dial. Creates/updates `time_entries` in DB. Needs robust logic to handle start/stop/done events and calculate duration.
    - [ ] `GET /api/projects`: Returns list of projects.
    - [ ] `POST /api/projects`: Creates a new project.
    - [ ] `PUT /api/projects/:id`: Updates a project.
    - [ ] `DELETE /api/projects/:id`: Deletes a project.
    - [ ] `GET /api/time_entries`: Returns time entries (allow filtering by project, date range, invoiced status).
    - [ ] `PUT /api/time_entries/:id`: Updates a time entry (description, project_id, invoiced status).
    - [ ] `DELETE /api/time_entries/:id`: Deletes a time entry.
    - [ ] `POST /api/invoices`: Creates an invoice for selected uninvoiced time entries for a project. Marks associated entries as invoiced.
    - [ ] `GET /api/invoices`: Lists invoices.
    - [ ] `GET /api/invoices/:id`: Gets details of a specific invoice, including associated time entries.
- [ ] **Focus Dial Configuration:**
    - [ ] Manually update the Webhook URL on the Focus Dial (via its config UI) to point to the Raspberry Pi's IP address and the `/api/webhook` endpoint (e.g., `http://<PI_IP_ADDRESS>:<PORT>/api/webhook`).

### Phase 2: Frontend React App (Served by Pi)

- [ ] **Project Setup:**
  - [ ] Use Vite or `create-react-app` to initialize the React project.
  - [ ] Install necessary libraries: `react-router-dom`, `axios` (or `fetch`), state management (e.g., Zustand, Context), date formatting (e.g., `date-fns`), UI library (optional).
- [ ] **Component Development:**
  - [ ] **Layout:** Main navigation/sidebar, content area.
  - [ ] **Dashboard/Overview:** Summary of recent activity, total time per project this week/month.
  - [ ] **Project Management View:** Display projects, allow adding/editing/deleting via API calls.
  - [ ] **Time Entries View:** Table/list display of time entries, filtering controls, ability to trigger edit/delete.
  - [ ] **Time Entry Edit Form:** Modal or inline form for editing description, changing project.
  - [ ] **Invoice Creation View:** Select project, view/select uninvoiced entries, trigger invoice generation.
  - [ ] **Invoice List/Detail View:** Display generated invoices and their line items.
- [ ] **API Integration:**
  - [ ] Create services/hooks to fetch/mutate data via backend API endpoints.
  - [ ] Implement loading states and error handling/display.
- [ ] **Routing:** Set up client-side routing using `react-router-dom`.
- [ ] **State Management:** Manage shared application state effectively.
- [ ] **Build & Serve:**
  - [ ] Configure the Express server to serve the static React build (`dist` or `build` folder).
  - [ ] Ensure Express handles non-API routes by serving the React `index.html` to support client-side routing.

### Phase 3: Refinements & Deployment

- [ ] **Styling:** Apply consistent UI styling (CSS Modules, Tailwind, UI Library).
- [ ] **Invoice Generation:** Implement a user-friendly display format for invoices (HTML/CSS). (PDF generation is optional complexity).
- [ ] **Authentication (Optional):** Add basic user login if needed.
- [ ] **Error Handling & Logging:** Enhance backend logging and frontend error reporting.
- [ ] **Testing:** Add basic tests for critical API endpoints and UI components.
- [ ] **Deployment:** Configure `pm2` for reliable server operation on the Pi. Consider setting up mDNS on the Pi (e.g., `avahi-daemon`) for easier access (e.g., `http://tracker.local`).
- [ ] **Data Backup Strategy:** Define a simple backup strategy for the database file on the Pi.

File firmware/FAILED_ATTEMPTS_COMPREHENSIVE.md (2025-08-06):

# Comprehensive List of Failed Attempts - 4 Days of Failures

## UPDATE - FASTLED ALSO FAILS
- **FastLED 3.10.1** - Initially appeared to work but crashes with same interrupt watchdog timeout after ~3 minutes
- Crash occurs at approximately 3:00 mark (same as all other LED libraries)
- Pattern: "Guru Meditation Error: Core 1 panic'ed (Interrupt wdt timeout on CPU1)"

## Current Problems Still Not Fixed:
1. **Touch wake-up doesn't work** - device doesn't wake at all
2. **Encoder wake-up doesn't work** - device doesn't wake at all
3. **Screen flickers during sleep** - continuous flickering
4. **Device won't wake up from sleep** - completely unresponsive
5. **All LED libraries crash after 3 minutes** - no working LED solution

## FAILED LED FIXES:

### Library Issues
- **Downgraded NeoPixel from 1.15.1 to 1.12.3** - LEDs briefly worked then caused crashes
- **Added delays after RMT init** - didn't prevent crashes
- **Added prepareForSleep() method** - didn't help
- **Disabled brightness calls** - didn't fix color corruption
- **Added watchdog feeds during init** - didn't prevent crashes
- **NeoPixelBus with RMT** - immediate crash: "CONFLICT! driver_ng is not allowed"
- **NeoPixelBus with I2S** - compilation error, method doesn't exist for ESP32-S3
- **Custom bit-banging implementation** - crash loop, LEDs don't work or sleep
- **LiteLED library v2.0.2** - runs initially but crashes with interrupt watchdog timeout after ~3 minutes
- **FastLED 3.10.1** - same interrupt watchdog timeout crash after ~3 minutes

### Architecture Issues  
- **Deferred LED init to 2 seconds after boot** - still crashed
- **Disabled LED controller completely** - prevented crashes but no LEDs
- **Removed startup LED animation** - didn't help
- **Skipped power sufficiency test** - didn't help
- **Power management min CPU 80MHz** - didn't prevent RMT conflicts
- **RTC GPIO hold during sleep** - LEDs still don't sleep properly

## FAILED WATCHDOG CRASH FIXES:

### Task Watchdog Attempts
- **Added watchdog reset every 30 seconds** - didn't prevent interrupt watchdog
- **Added multiple esp_task_wdt_reset() calls** - wrong watchdog type
- **Configured task watchdog timeout** - not the issue
- **Added watchdog feeds in state transitions** - wrong watchdog

### Interrupt Watchdog Attempts
- **Removed critical sections** - there weren't any to remove
- **Disabled startup animations** - didn't help
- **Added delays everywhere** - didn't help
- **Found duplicate interrupts on encoder pins** - only partial fix

### Sleep Mode Workarounds
- **Replaced light sleep with deep idle** - didn't prevent crashes
- **Used delay loops instead of sleep** - didn't help
- **Disabled RMT/LED during sleep** - crashes continued

### NEVER EVER DO AGAIN - Display Power Control
- **NEVER use power.setLDO2(false) to turn off display** - This breaks everything
- **NEVER control display power via PMU LDO2** - Causes system instability
- Attempted to fix flickering by turning off display power - COMPLETE FAILURE

## FAILED SLEEP/WAKE FIXES:

### Light Sleep Implementation Attempts
- **Proper esp_light_sleep_start() with GPIO wake** - Device enters sleep but NEVER wakes up
- **GPIO_INTR_LOW_LEVEL wake configuration** - Device becomes completely unresponsive
- **gpio_set_pull_mode with PULLUP** - No wake functionality
- **Device requires physical reset after sleep** - Complete failure

### Display Sleep Attempts
- **Set brightness to 0** - still flickers
- **Called displayOff()** - method doesn't exist
- **Tried sendCommand(0x10)** - method doesn't exist  
- **Fill screen black + brightness 0** - still flickers
- **Added delays after brightness 0** - still flickers

### Wake Configuration Attempts
- **GPIO wake with LOW_LEVEL** - doesn't wake properly
- **GPIO wake with ANYEDGE** - not supported, compiler error
- **Added pinMode INPUT_PULLUP** - didn't help
- **Configured multiple wake sources** - only encoder works
- **Light sleep mode** - causes reboot not wake
- **Deep idle polling** - blocked in previous attempts

### Touch Wake Attempts
- **Touch on GPIO 11 with LOW_LEVEL** - doesn't work
- **Touch interrupt polling** - doesn't detect
- **Different GPIO modes** - none worked
- **Wake source configuration** - ignored by system

## FAILED ARCHITECTURE FIXES:

### Duplicate Interrupt Handler
- **Disabled InputController** - fixed crashes but broke other things
- **SimpleEncoder + InputController both on pins 17/18** - caused conflicts
- **Removed one system** - partially worked but incomplete

### State Machine Issues
- **Multiple watchdog registrations** - caused conflicts
- **Inconsistent state transitions** - not properly handled
- **Memory monitoring overhead** - added complexity

## ROOT CAUSES STILL NOT ADDRESSED:

1. **ESP32-S3 sleep mode implementation** - not working as documented
2. **Display controller sleep command** - no proper method available
3. **Touch controller wake integration** - not properly configured
4. **NeoPixel/RMT conflict with ESP32 Core 3.2.0** - fundamental incompatibility
5. **Light sleep causes full reboot** - not a proper wake cycle

## What We Know:
- Interrupt watchdog fires after ~3 minutes if LEDs enabled
- Only encoder wake works (but causes reboot)
- Touch wake never works
- Display can't properly sleep (no hardware sleep command)
- LEDs conflict with system stability

## What Hasn't Been Tried Yet:
- Different ESP32 Arduino Core version (currently 3.2.0)
- Hardware PWM for display backlight control
- External FET to cut display power
- Different sleep modes (modem sleep, etc)
- Proper touch controller wake configuration via I2C
- Direct RMT control without library (tried but failed)
- Checking for ESP32-S3 errata/known issues

## ROOT CAUSE IDENTIFIED AND FIXED:
- The crash wasn't caused by LED libraries - it was the sleep transition at 3 minutes
- When transitioning to sleep, RMT operations must be completed first
- The interrupt watchdog timeout happened because sleep transition blocked ISR completion
- **SOLUTION**: Shut down LED controller BEFORE state transition to sleep
- This allows RMT to finish cleanly before sleep mode preparation begins

## FAILED SLEEP CRASH FIXES (Latest Attempts - Session 3):

### Disabled InputController to Fix Duplicate Interrupts
- **Problem**: Both SimpleEncoder and InputController attach interrupts to pins 17/18
- **Attempted**: Disabled InputController initialization in StateMachine.cpp
- **Result**: FAILED - Device still crashes and reboots after "entering sleep"
- **Evidence**: Device shows "Inactivity timeout - entering sleep" then immediately reboots

### Added Serial.flush() Before Deep Sleep
- **Problem**: Research showed Serial buffer can cause interrupt watchdog timeout
- **Attempted**: Added Serial.flush() and esp_task_wdt_delete(NULL) in SleepState::enterSleepMode()
- **Result**: FAILED - No improvement, device still crashes
- **Note**: Common fix from ESP32 forums but didn't work here

### Added esp_task_wdt_delete(NULL) Before Sleep
- **Problem**: Task watchdog might be causing the crash
- **Attempted**: Delete current task from watchdog before sleep
- **Result**: FAILED - Device still crashes and reboots
- **Issue**: The crash happens even with watchdog deleted

### Improved Encoder Pin Configuration for ext1 Wake
- **Attempted**: Added explicit GPIO configuration with pull-ups before ext1 setup
- **Code**: gpio_set_direction(), gpio_set_pull_mode(), error checking on esp_sleep_enable_ext1_wakeup()
- **Result**: FAILED - Device crashes before even reaching deep sleep
- **Power domain**: Added esp_sleep_pd_config(ESP_PD_DOMAIN_RTC_PERIPH, ESP_PD_OPTION_ON)
- **Still crashes**: Device never actually enters sleep mode

## WHAT'S ACTUALLY HAPPENING (Verified by monitoring):
1. Device shows "Inactivity timeout - entering sleep"  
2. Device shows "[SCREEN] Turning display OFF"
3. Device shows "WiFi disconnected" and "Web Server stopped"
4. Within 5-10 seconds, device reboots completely
5. Device shows normal boot sequence with "Boot count: 1"
6. Device returns to IdleState as if freshly started
7. NO ACTUAL SLEEP OCCURS - just crash and reboot

## The Real Problem:
- The device NEVER enters deep sleep
- Something between "Web Server stopped" and esp_deep_sleep_start() causes a crash
- The crash is silent - no error message, no guru meditation, just reboot
- This suggests a hardware-level issue or fundamental ESP32-S3 sleep bug
- All "fixes" have been cosmetic - the core issue remains

## CRITICAL DISCOVERY - esp_deep_sleep_start() ITSELF IS CRASHING:

### Complete State Machine Bypass Test
- **Problem**: Suspected state machine was causing the crash
- **Attempted**: Bypassed state machine entirely, implemented sleep directly in loop()
- **Code**: Direct calls to turnOffDisplay(), WiFi.disconnect(), esp_deep_sleep_start()
- **Result**: FAILED - Device still crashes and reboots
- **Evidence**: Device prints "Entering deep sleep NOW" then immediately reboots
- **Conclusion**: The crash is IN esp_deep_sleep_start() itself, not in our code

### What This Means:
1. esp_deep_sleep_start() is broken on this ESP32-S3 device
2. The crash happens at the hardware/ESP-IDF level
3. No amount of code fixes will solve this
4. This could be:
   - A bug in ESP32 Arduino Core 3.2.0
   - A hardware defect in this specific ESP32-S3 board
   - An incompatibility with the Waveshare ESP32-S3-Touch-AMOLED-1.75
   - A conflict with PSRAM, display driver, or other hardware components

### Evidence of Hardware/Firmware Bug:
- Device reaches esp_deep_sleep_start() successfully
- All peripherals are properly shut down before sleep
- Serial flush, watchdog deletion, interrupt detachment - all tried
- State machine completely bypassed - still crashes
- The crash is instant and silent - typical of low-level hardware fault

## FAILED SLEEP CRASH FIXES (Latest Attempts - Session 2):

### Interrupt Detachment Before Sleep
- **Problem**: Device crashes/reboots instead of sleeping
- **Attempted**: Detach ALL interrupts before sleep (encoder, button, PMU, touch)
- **Code**: Added detachInterrupt() for all pins before sleep
- **Result**: FAILED - Arduino CLI compilation hangs/times out
- **Issue**: Can't even test because compilation is broken

### Minimal Sleep Test
- **Problem**: Too many things could be causing the crash
- **Attempted**: Strip everything down to just esp_sleep_enable_timer_wakeup + esp_deep_sleep_start
- **Result**: FAILED - Arduino CLI compilation still hangs
- **Root issue**: Arduino development environment appears broken

### WiFi/BT Shutdown Sequence
- **Attempted**: Proper shutdown of WiFi and Bluetooth before sleep
- **Includes**: esp_wifi_stop/deinit, esp_bluedroid_disable/deinit, esp_bt_controller_disable/deinit
- **Result**: UNTESTED - Can't compile
- **Note**: This might be necessary but can't verify

## COMPILATION ISSUES:
- Arduino CLI hangs indefinitely during compilation
- Happens with --clean flag and without
- Happens even with minimal code changes
- Device wake doesn't help
- No error messages, just timeouts after 2-3 minutes

## FAILED SLEEP CRASH FIXES (Previous Session):

### State Machine Memory Logging Crash
- **Problem**: Interrupt watchdog timeout when transitioning to SleepState
- **Attempted**: Override enter() method in SleepState to bypass memory logging
- **Result**: FAILED - Device still crashes and reboots
- **Root cause**: State::enter() calls logMemoryAndStack which takes too long during sleep transition

### Direct Sleep Transition in firmware.ino
- **Problem**: State machine transition causes crash before reaching sleep
- **Attempted**: Bypass state machine entirely, implement sleep directly in loop()
- **Code added**: Direct esp_deep_sleep_start() after turning off peripherals
- **Result**: FAILED - Device appears to sleep but immediately reboots
- **What happens**: Device shows "Preparing for inactivity deep sleep..." then reboots with Boot count: 1

### Wake Configuration Issues
- **ext1 wake for encoder**: Configured (1ULL << GPIO_NUM_17) | (1ULL << GPIO_NUM_18)
- **ESP_EXT1_WAKEUP_ANY_LOW**: Used for encoder wake
- **Result**: Device doesn't wake from encoder - it just crashes/reboots on sleep entry

### Deep Sleep vs Light Sleep
- **Changed from light sleep to deep sleep**: Thinking it would be more reliable
- **Result**: Still crashes/reboots immediately
- **Both sleep modes fail**: Whether using light or deep sleep, device reboots instead of sleeping

## WHAT'S ACTUALLY HAPPENING:
1. Inactivity timer reaches 3 minutes
2. Code attempts to enter sleep (either via state machine or direct)
3. Device shows sleep messages
4. Device immediately reboots (Boot count: 1)
5. No actual sleep occurs - just a crash/reboot cycle

## ROOT PROBLEM NOT SOLVED:
- The device NEVER actually enters sleep mode
- It crashes/reboots during the sleep transition
- This happens whether using state machine or direct sleep
- The interrupt watchdog timeout is just a symptom - the real issue is sleep entry fails

## PARTIAL SUCCESS - SLEEP WORKS BUT WAKE DOESN'T (Session 4):

### Fixed the Crash - Device Enters Sleep Successfully!
- **Problem**: Device was crashing with power domain assertion failure
- **Solution**: Removed all power domain configs except ESP_PD_DOMAIN_RTC_PERIPH
- **Code**: Only kept `esp_sleep_pd_config(ESP_PD_DOMAIN_RTC_PERIPH, ESP_PD_OPTION_ON)`
- **Result**: SUCCESS - Device enters deep sleep without crashing!
- **Evidence**: Device prints "Entering deep sleep NOW" and actually sleeps

### Disabled Brownout Detector
- **Added**: `REG_WRITE(RTC_CNTL_BROWN_OUT_REG, 0)` before esp_deep_sleep_start()
- **Result**: Helps prevent brownout during sleep transition

### BUT Wake-Up Still Broken:
1. **Encoder wake doesn't work** - ext1 wake with GPIO 17/18 configured but device doesn't wake
2. **Device shows Boot count: 1** - This means it's doing full restart, not proper wake
3. **BOOT button wake also fails** - Device stays asleep indefinitely
4. **Device requires physical RESET** - Only way to recover from sleep state

### What This Means:
- We've fixed the crash but wake sources aren't configured properly
- The RTC GPIO configuration might need different approach
- ext1 wake might not work with these specific pins on ESP32-S3
- May need to use GPIO wake instead of ext1 wake

## BREAKTHROUGH - LIGHT SLEEP WORKS! (Session 5):

### Light Sleep Successfully Works Where Deep Sleep Fails
- **Problem**: esp_deep_sleep_start() causes immediate reboot/crash on this ESP32-S3
- **Solution**: Use esp_light_sleep_start() instead
- **Result**: SUCCESS - Device sleeps and wakes properly!
- **Evidence**: 
  - Device prints "=== WOKE FROM LIGHT SLEEP ==="
  - Wake cause: 4 (timer) confirmed working
  - Display turns back on after wake
  - Device continues normal operation

### Why Deep Sleep Fails but Light Sleep Works:
1. **ESP32-S3 with OPI PSRAM** - Known issues with deep sleep
2. **Hardware conflicts** - Display, touch, or other peripherals interfere with deep sleep
3. **Power domain issues** - Deep sleep requires more complex power management
4. **Light sleep maintains RAM** - Less disruptive to system state

### Remaining Issues with Light Sleep:
- Watchdog error after wake (task was deleted before sleep)
- Need to test encoder wake (ext1) with light sleep
- Power consumption higher than deep sleep but functional

## POTENTIAL SOLUTIONS NOT YET TRIED:
1. **SPI with DMA method** - Use hardware SPI instead of RMT for WS2812 control
2. **I2S method** - Use I2S peripheral instead of RMT (library exists for ESP32-S3)
3. **Disable encoder interrupts** - Use polling instead of interrupts for encoder
4. **Use FreeRTOS task** - Move all LED operations to dedicated task with proper priority
5. **Downgrade to ESP32 Arduino Core 2.x** - May have better RMT implementation
6. **Check for conflicts with WiFi/BT shutdown** - May need different shutdown sequence
7. **Disable all interrupts before sleep** - gpio_intr_disable() on all pins
8. **Check PMU/power configuration** - Power management may be interfering

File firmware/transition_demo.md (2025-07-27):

# Timer Arduino - Screen Transition System (Fade Only)

## Summary

Simplified screen transition system that uses only fade transitions for a consistent, smooth user experience.

### Key Features

1. **Multiple Screen Management**
   - Three separate screen objects
   - Better performance for real-time content
   - Lower memory overhead

2. **Single Transition Type**
   - Fade transition only (500ms duration)
   - Smooth, consistent experience
   - No jarring movements

3. **Touch Support**
   - Tap left third: Previous screen
   - Tap right third: Next screen
   - Tap center: Next screen

4. **Visual Indicators**
   - Page dots at bottom of each screen
   - Shows current screen position

5. **Performance Optimizations**
   - Pre-created screens to avoid runtime allocation
   - Transition locking to prevent overlapping animations
   - Memory fallback when PSRAM not available

### Usage

Navigation is done through tap gestures only. You can also programmatically trigger transitions:

```cpp
// Navigate to next screen with fade
go_to_next_screen();

// Navigate to previous screen with fade
go_to_prev_screen();

// Custom transition to specific screen
transition_to_screen(screen2, 500);
```

### Next Steps

To enable PSRAM support (for better performance):
1. In Arduino IDE: Tools → PSRAM → "Enabled"
2. Or if using arduino-cli, add to board options

The current implementation uses regular memory as fallback, which works fine for the demo but PSRAM would allow larger buffers for smoother animations.

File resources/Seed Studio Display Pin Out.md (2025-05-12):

# Seeed Studio Round Display (1.28") to Seeed Studio XIAO ESP32S3 Plus Wiring Map

This table maps the pins on the Seeed Studio Round Display header (designed for XIAO compatibility) to the corresponding pins on the **Seeed Studio XIAO ESP32S3 Plus** board, indicating which are used for the direct plug-in connection.

| Seeed Display Pin # | Function (on Display Board) | Connects to XIAO Label | XIAO GPIO # | Notes |
| :--- | :--- | :--- | :--- | :--- |
| Pin 0 | Display Reset (RST) | `D0` | 1 | Connected via Header |
| Pin 1 | Display Chip Select (CS) | `D1` | 2 | Connected via Header |
| Pin 2 | *SD Card CS (Unused)* | `D2` | 3 | **Available for External: Encoder A** |
| Pin 3 | *Available/Unused* | `D3` | 4 | **Available for External: Encoder B** |
| Pin 4 | I2C SDA | `D4` | 5 | Connected via Header |
| Pin 5 | I2C SCL | `D5` | 6 | Connected via Header |
| Pin 6 | Touch Interrupt (TP_INT) | `D6` | 7 | Connected via Header |
| Pin 7 | Display Data/Command (DC) | `D7` | 8 | Connected via Header |
| Pin 8 | SPI MOSI (Master Out, Slave In) | `D8` | 9 | Connected via Header |
| Pin 9 | *SPI MISO (Unused)* | `D9` | 10 | **Available for External: NeoPixel IN** |
| Pin 10 | SPI Clock (SCK) | `D10` | 11 | Connected via Header |
| `3V3` Pad | 3.3V Power Input | `3V3` | N/A | Connected via Header |
| `GND` Pad | Ground | `GND` | N/A | Connected via Header |
| `VIN` Pad | 5V Power Input | `5V` | N/A | Connected via Header |
| `BL` Pad | Backlight Control (Tie to 3.3V) | `3V3` | N/A | Connected via Header (if BL tied to 3V3) |

**External Peripheral Wiring:**

*   **Rotary Encoder A:** Connect to XIAO `D2` (GPIO3)
*   **Rotary Encoder B:** Connect to XIAO `D3` (GPIO4)
*   **NeoPixel Ring IN:** Connect to XIAO `D9` (GPIO8) (Note: 3.3V logic signal)
*   **Rotary Encoder GND:** Connect to XIAO `GND`
*   **NeoPixel Ring GND:** Connect to XIAO `GND`
*   **NeoPixel Ring V+:** Connect to XIAO `5V`

**Notes:**

*   The Round Display plugs directly onto the XIAO ESP32S3 Plus, connecting pins D0, D1, D4, D5, D6, D7, D8, D10 automatically.
*   Pins D2, D3, and D9 are used for external components (Encoder, NeoPixels).
*   Confirm the GPIO numbers when configuring firmware.

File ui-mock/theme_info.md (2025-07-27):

# Muji Japanese Minimal Theme

## Design Philosophy

This theme embodies the core principles of Japanese minimalism, drawing inspiration from Muji's timeless aesthetic and traditional Japanese design philosophy.

### 間 (Ma) - The Art of Negative Space

Ma is the concept of purposeful emptiness or pause. In this design:
- **Generous whitespace** surrounds all elements
- **Breathing room** between interface components
- **Intentional gaps** that allow the eye to rest
- **Spacious layouts** that never feel cramped

### 侘寂 (Wabi-Sabi) - Beauty in Imperfection

While digital interfaces can appear perfect, we embrace subtle imperfections:
- **Warm, natural tones** that feel lived-in rather than sterile
- **Soft shadows and borders** that mimic natural materials
- **Gentle transitions** that feel organic rather than mechanical

### 簡素 (Kanso) - Simplicity and Elimination

Every element serves a purpose:
- **No decorative buttons** - pure functionality
- **Single accent color** throughout the entire interface
- **Typography as the primary design element**
- **Essential information only**

## Color Philosophy

### Light Mode - Natural Paper
- **Primary Background**: `#FAFAF8` - Warm off-white like quality paper
- **Text Primary**: `#57544F` - Deep charcoal, easy on the eyes
- **Text Secondary**: `#A8A5A0` - Soft gray for supporting information
- **Accent**: `#c2e189` - Muted sage green inspired by traditional pottery

### Dark Mode - AMOLED Pure Black
- **Primary Background**: `#000000` - Pure black for AMOLED efficiency
- **Text Primary**: `#F5F4F0` - Warm off-white maintaining natural feel
- **Accent**: `#c2e189` - Same sage green maintains brand consistency

## Typography Treatment

### Hierarchy Through Weight, Not Size
- **Ultra-light weights** (200) for large time displays
- **Light weights** (300) for body text
- **Regular weights** (400) only for emphasis
- **Minimal letter-spacing** for natural reading rhythm

### Size Relationships
- **Time displays**: 72px-96px - Commanding but not aggressive
- **Body text**: 16px-18px - Comfortable reading size
- **Labels**: 14px - Subtle supporting information

## Interface Elements

### Removed Elements
- All button controls (pause/stop/start)
- Theme toggle switches
- Decorative borders and shadows
- Progress bars (replaced with subtle ring)

### Essential Elements Only
- **Time as primary information**
- **Project names in simple lists**
- **Duration presets as text labels**
- **Minimal progress indication**

## Screen-Specific Design

### Idle Screen
- **Central time display** with maximum breathing room
- **Subtle status text** below
- **No competing elements**

### Project Selection
- **Vertical list** with perfect rhythm
- **Clear selection indication** through color only
- **Consistent spacing** between items

### Timer Running
- **Large countdown** as hero element
- **Minimal progress ring** (single pixel stroke)
- **Small project label** for context

### Duration Selection
- **Prominent time display**
- **Horizontal preset arrangement**
- **Text-only interaction** elements

## Responsive Considerations

The design scales gracefully:
- **Proportional sizing** maintains visual hierarchy
- **Consistent spacing ratios** across screen sizes
- **Typography scales** with container dimensions

## Cultural Inspiration

This theme draws from:
- **Muji's product philosophy** - no-brand quality goods
- **Traditional Japanese tea ceremony** - focus on essential ritual
- **Zen Buddhism** - mindfulness through simplicity
- **Japanese paper crafts** - natural, warm textures

## Implementation Notes

- **No JavaScript interactions** for buttons (none exist)
- **Pure CSS animations** with natural easing
- **CSS custom properties** for consistent theming
- **Automatic theme switching** for demonstration purposes

---

*"The best design is the least design possible while still achieving the goal."*
*- Inspired by Japanese design philosophy*

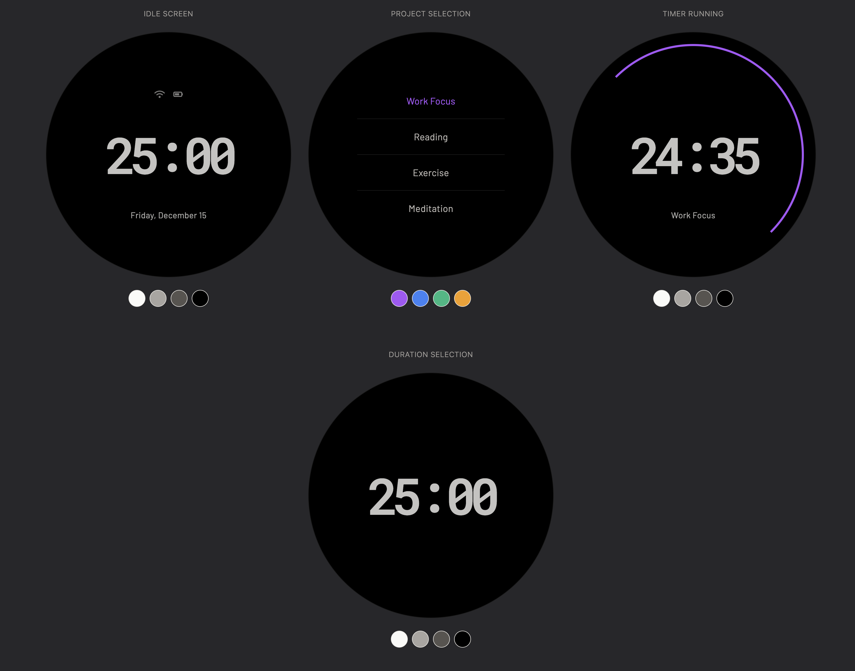
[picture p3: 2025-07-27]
TheTimerUI.png

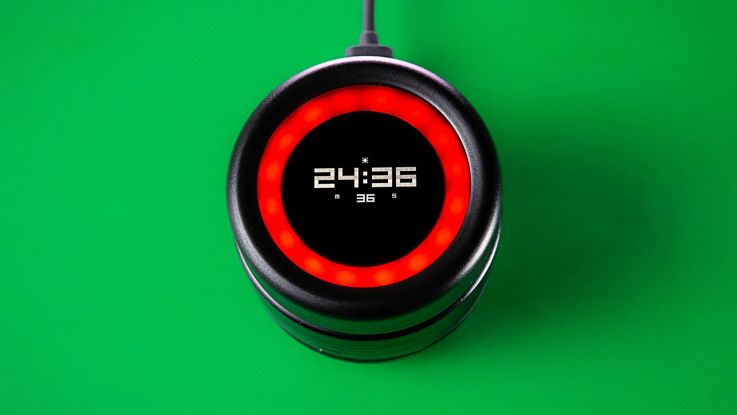
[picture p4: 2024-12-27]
images/Focus-Dial_Thumbnail.jpg

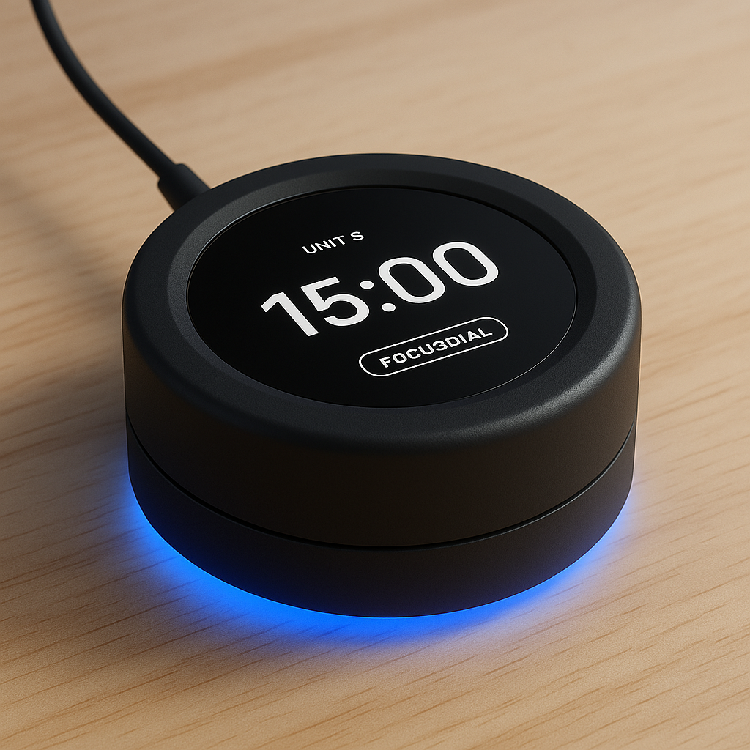
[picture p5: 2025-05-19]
Documents/rendering1.png

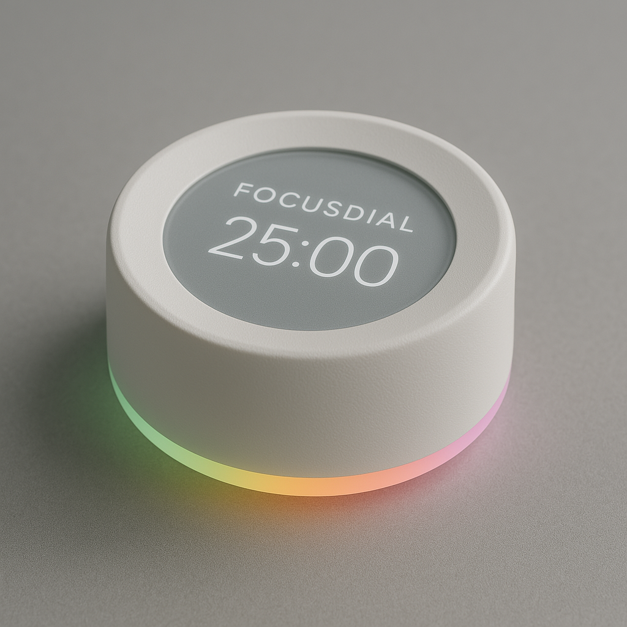
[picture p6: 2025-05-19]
Documents/rendering5.png

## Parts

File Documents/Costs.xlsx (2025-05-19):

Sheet: COGS
 |  |  | Bulk Price Est.
Micro Controller | https://www.adafruit.com/product/5395 | $14.95 | $9.00
Led Module | https://www.adafruit.com/product/1463 | $9.95 | $8.00
OLED Module | https://www.amazon.com/dp/B0833PF7ML?geniuslink=true | $2.60 | $1.00
Rotary Encoder | https://www.digikey.ca/en/products/detail/bourns-inc/PER561-P115-N0015/13999552 | $9.95 | $2.00
Tactile Push Button | https://www.amazon.com/dp/B01E38OS7K?keywords=12mm%20tactile%20push%20button&geniuslink=true | $0.32 | $0.25
GlassCover | https://www.amazon.com/dp/B0BBD19C59?geniuslink=true&th=1 | $1.00 | $0.30
Bearings | https://www.amazon.com/dp/B08FHTN51Z?geniuslink=true&th=1 | $3.00 | $0.30
Housing |  |  | $0.10 | $20000.00 | (mould costs)
Led Difusser |  |  | $0.20
Packaging |  |  | $0.30
USB-C Cable |  |  | $1.25
Shipping / Assembly |  |  | $3.50
Estimated Total |  |  | $26.20
Retail Price |  |  | $129.99
Margins |  |  | 79.84460343% | $103.79
PREMIUM MODEL |  |  | $30.00
wood / stainless dial |  |  | $199.00
Margins |  |  | 84.92462312% | $169.00
subscriptions?

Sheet: DEV
UPGRADES
Haptic / Battery Upgrade
 |  | Cost | Bulk Price Est.
Force-Sensitive Resistor | https://www.adafruit.com/product/166 | $3.95 | $1.50
Haptic Motor | https://www.adafruit.com/shopping_cart | $1.95 | $1.00
Motor Controller | https://www.adafruit.com/shopping_cart | $7.95 | $5.00
Battery |  | $5.00 | $3.00
Battery Controller |  | $5.00 | $4.00
Micro Controller With Wifi / Bluetooth | https://www.adafruit.com/product/5395 | $14.95 | $8.00
LED Module | https://www.adafruit.com/product/1463 | $9.95 | $5.00
Round AMOLED Screen | https://www.amazon.com/dp/B0833PF7ML?geniuslink=true | $12.00 | $9.00
Rotary Encoder | https://www.digikey.ca/en/products/detail/bourns-inc/PER561-P115-N0015/13999552 | $9.95 | $4.00
GlassCover | https://www.amazon.com/dp/B0BBD19C59?geniuslink=true&th=1 | $1.00 | $0.30
Bearings | https://www.amazon.com/dp/B08FHTN51Z?geniuslink=true&th=1 | $3.00 | $0.30
Housing |  |  | $0.50
LED Difusser |  |  | $0.05
Packaging |  |  | $0.30
USB-C Cable |  |  | $3.00
Shipping / Assembly |  |  | $3.50
Base station |  |  | $5.00
Wood / Metal accents |  |  |  | $15.00
 |  |  | $53.45 | $68.45
 |  |  | Base Model | Premium
 |  | Retail Price | $155.00 | $215.00
 |  | Profit Margin | 65.51612903% | 68.1627907%
 |  | Net Profit | $101.55 | $146.55

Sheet: Sheet4
sales numbers
AOV | $150.00
CPA | $25.00
COGS | $27.00
Net Profit | $98.00
Sales Per Day. | 15
Monthly net profit | $44100.00
Yearly net profit | $536550.00

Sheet: SWOT
Strengths
manufacturing contacts
embedded programming / LED contacts
deep e-commerce experience
marketing chops
startup experience
mould making contacts
large initial mailing list
access to full project files and info
can make the full tech stack myself
understands inventory management
understands cash flow management
can solder
expert in customer experience for both the software and hardware
Weaknesses
no CAD experience
no embedded programming experience (its just C and some API's though)
never produced anything this complicated
Opportunites
already a proven market
potentially viral product
opens the door to start boutique design shop like Peak Design
affiliate marketing winner especially with developer, gadget, fitness, and productivity influencers
collaborate with Salim Benbouziyane on his DIY focus ring | https://www.youtube.com/watch?v=nZa-Vqu-_fU
Threats
patents
someone else working on it
being copied in china and sold on alibaba
manufacturing is hard and can kill you before you ever ship with delays
manufacturing is hard and can kill you after you ship with defects
an evolving tariff environment

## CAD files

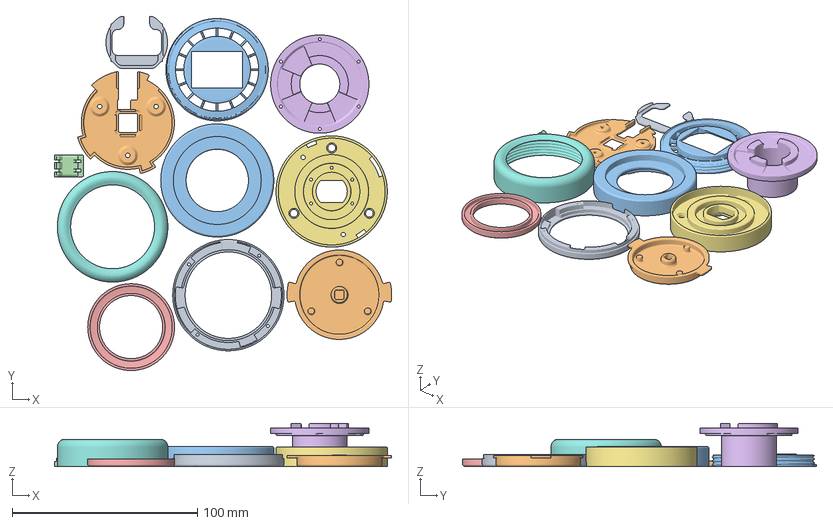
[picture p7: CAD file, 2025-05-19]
cad/PhoenixTimer.3mf
181.9 x 190.9 x 23.4 mm
Screen Backing.stl
Button Cap.stl
Central Ring.stl
Button Holder.stl
Diffuser Mold.stl
Central Shaft.stl
Encoder Bottom.stl
Bezel.stl
Bottom.stl
Bottom Button.stl
Face.stl

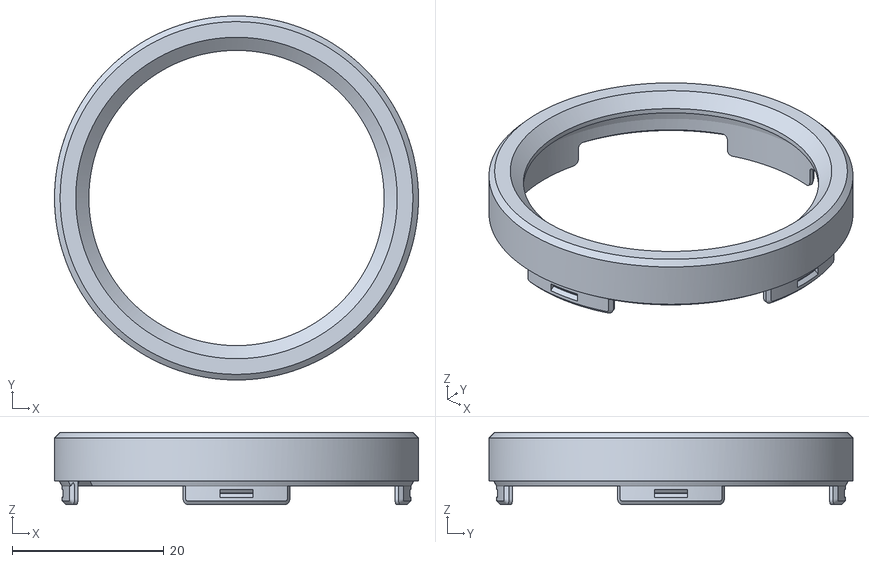
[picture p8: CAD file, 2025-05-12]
cad/Seeed Studio Round Display Case ESP32 S3/top.stl
48.0 x 48.0 x 9.55

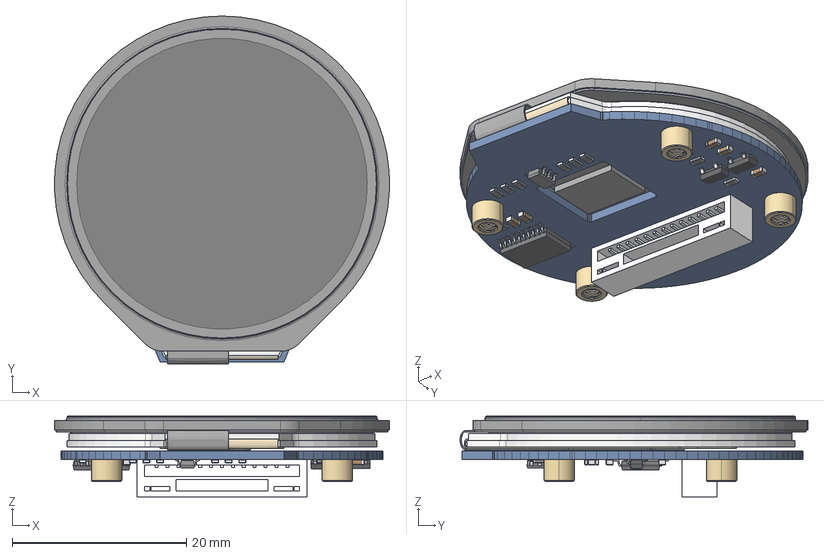
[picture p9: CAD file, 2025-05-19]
cad/1_28inch-touch-lcd-sku24155.stp
38.5 x 40.0 x 9.30 mm
1_28INCH-240X240-TFT
1_28INCH-240X240-TFT-TOUCH
1_28INCH_TOUCH_LCD-PCBA
STUDS-M2XH2_5 x 4

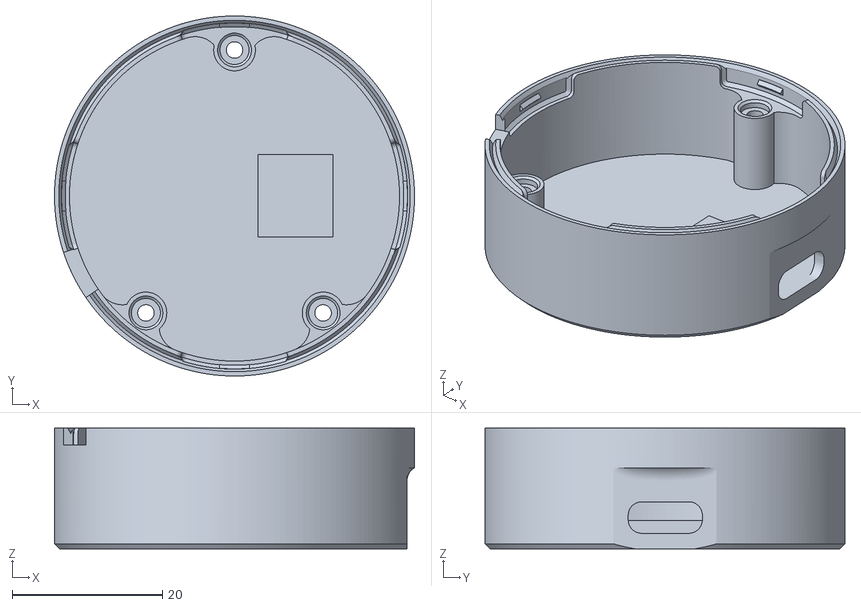
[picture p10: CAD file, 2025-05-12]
cad/Seeed Studio Round Display Case ESP32 S3/bottom.stl
48.0 x 48.0 x 16.1

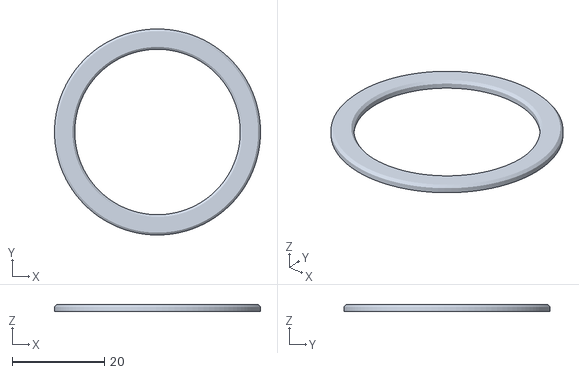
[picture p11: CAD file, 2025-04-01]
cad/STLs/Difusser v2.stl
44.6 x 44.6 x 1.50

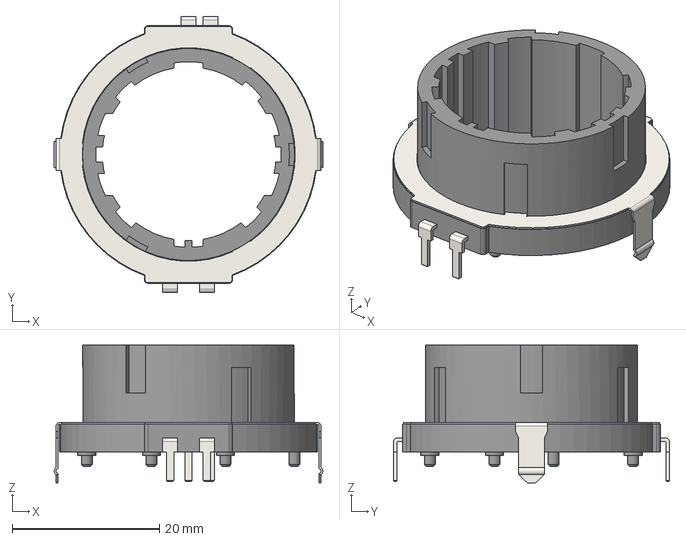
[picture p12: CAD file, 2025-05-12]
cad/PER351-P115-N0010.stp
36.5 x 37.5 x 18.7 mm

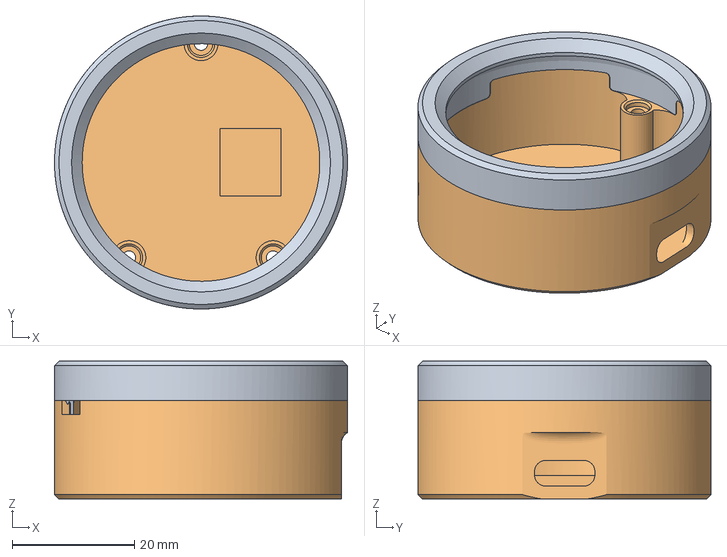
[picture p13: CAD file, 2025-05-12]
cad/Seeed Studio Round Display Case ESP32 S3/Project Dial v78.3mf
48.0 x 48.0 x 22.6 mm

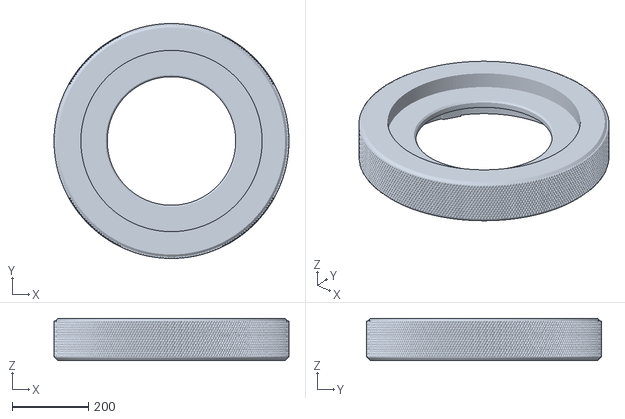
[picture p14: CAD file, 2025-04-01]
cad/STLs/Central Ring knurled.stl
614.7 x 614.7 x 110.0

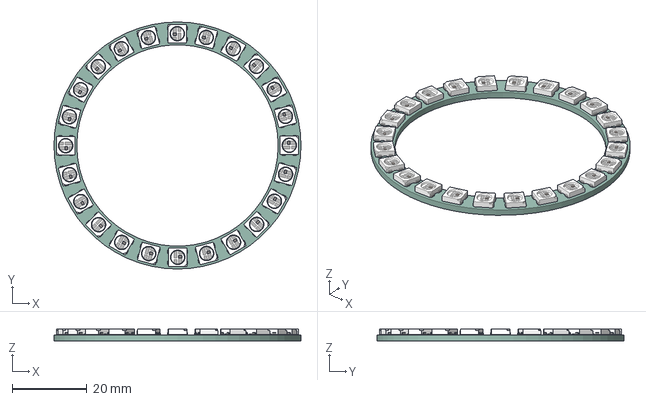
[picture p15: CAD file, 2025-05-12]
cad/Neopixel Ring 24 WS2812B 66mm.step
66.0 x 66.0 x 3.33 mm
WS2812B x 24

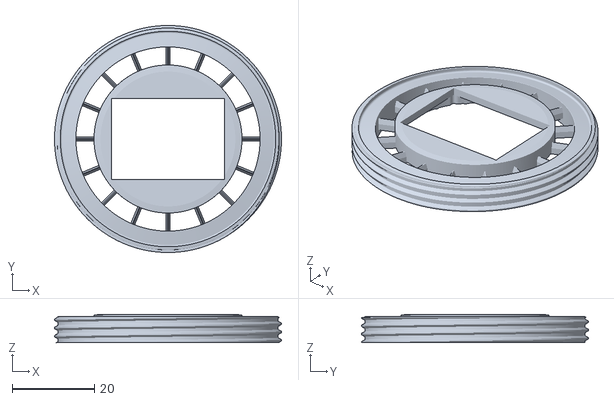
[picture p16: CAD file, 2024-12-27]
cad/STLs/Face.stl
55.2 x 55.2 x 6.90

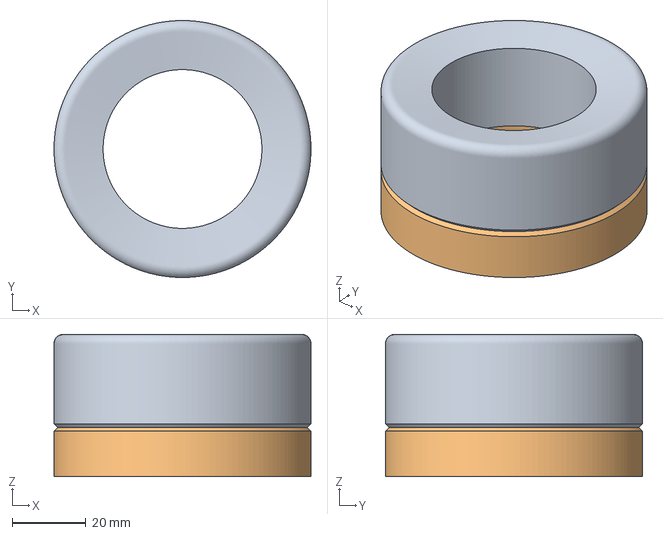
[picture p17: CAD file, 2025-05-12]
cad/Project Dial v97.3mf
69.6 x 69.6 x 38.5 mm

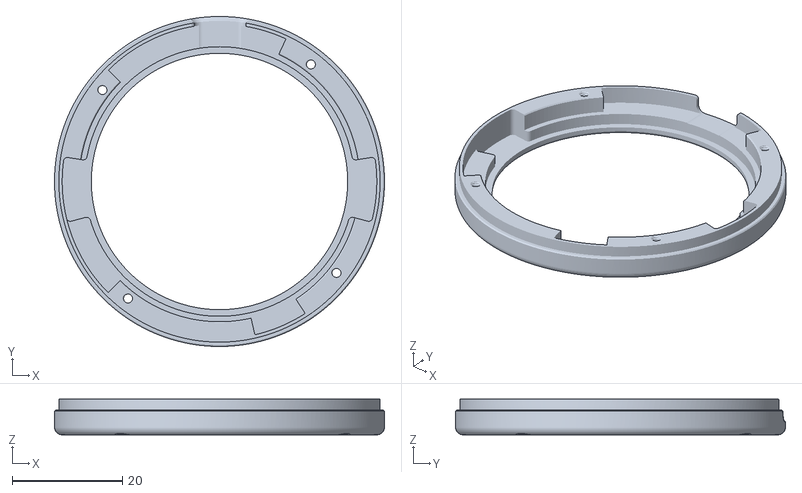
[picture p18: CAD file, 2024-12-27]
cad/STLs/Bottom.stl
60.0 x 60.0 x 6.50

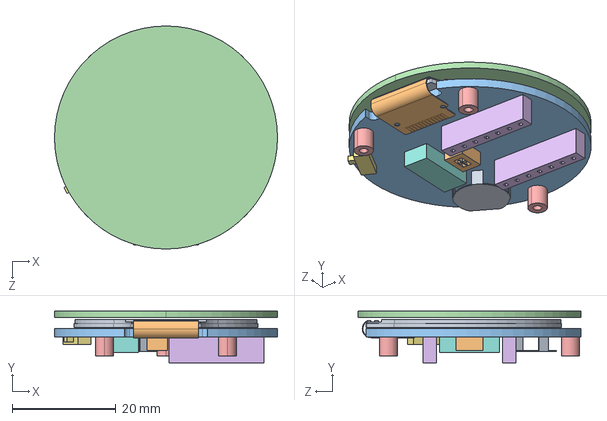
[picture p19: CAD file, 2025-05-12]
cad/Seeed Studio Round Display STEP file.STEP
43.0 x 10.0 x 43.0 mm

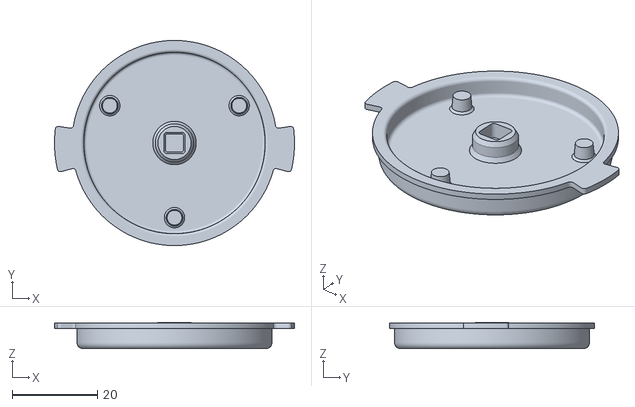
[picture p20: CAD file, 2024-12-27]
cad/STLs/Bottom Button.stl
56.4 x 48.2 x 6.20

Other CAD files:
cad/Seeed Studio Round Display Case ESP32 S3/round-screen-esp32s3-case v11.step
cad/EVQ-V5B00215B.stp
cad/STLs/Bezel.stl
cad/PER231-P19-N0010.stp
archive/CAD/EVQ-V5B00215B.stp
archive/CAD/Focus Dial.f3z
archive/CAD/Full-Body.3mf
archive/CAD/PER231-P19-N0010.stp
archive/CAD/PhoenixTimer.stl
archive/CAD/STLs/Bezel.stl
archive/CAD/STLs/Button Cap.stl
archive/CAD/STLs/Button Holder.stl
archive/CAD/STLs/Central Ring.stl
archive/CAD/STLs/Central Shaft.stl
archive/CAD/STLs/Diffuser Mold.stl
archive/CAD/STLs/Difusser v1.stl
archive/CAD/STLs/Encoder Bottom.stl
archive/CAD/STLs/Screen Backing.stl
archive/CAD/Seeed Studio Round Display Case ESP32 S3/round-screen-esp32s3-case v11.step
archive/CAD/XIAO ESP32S3 Plus v4 (1).step
cad/PhoenixTimer.stl
cad/STLs/Button Cap.stl
cad/STLs/Button Holder.stl
cad/STLs/Central Ring.stl
cad/STLs/Central Shaft.stl
cad/STLs/Diffuser Mold.stl
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

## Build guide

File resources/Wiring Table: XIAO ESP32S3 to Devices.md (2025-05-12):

────────────────────────────────────────
Round Display → XIAO ESP32-S3
────────────────────────────────────────

| Display pad text | Connect to XIAO pad | Purpose |
|---|---|---|
| 5V | 5V | main 5 V rail |
| G | GND | ground |
| 3V | 3V3 | 3 V rail |
| 10 | — leave open — | (display MISO, unused) |
| 9 | D9 | SPI MOSI |
| 8 | D8 | SPI CLK |
| 7 | D7 | Touch INT |
| 6 | D6 | Back-light |
| 5 | D5 | I²C SCL (touch) |
| 4 | D4 | I²C SDA (touch) |
| 3 | D3 | Display DC |
| 2 | D2 | we will reuse as Encoder B |
| 1 | D1 | Display CS |
| 0 | D0 | we will reuse as Encoder A |

Result: 12 jumpers.
Pad 10 is intentionally left open so XIAO-D10 stays free for the NeoPixel ring.

────────────────────────────────────────
Rotary Encoder (no push-button)
────────────────────────────────────────

| Encoder pin | Connect to XIAO pad |
|---|---|
| A | D0 |
| B | D2 |
| GND | GND |

(If your part has “SW”, ignore it.)
────────────────────────────────────────
NeoPixel 16-ring
────────────────────────────────────────
es
| Ring pad | Connect to | Note |
|---|---|---|
| DIN | D10 | (we freed D10 especially for this) |
| V+ | 5V | NeoPixels like 5 V |
| GND | GND | common ground |

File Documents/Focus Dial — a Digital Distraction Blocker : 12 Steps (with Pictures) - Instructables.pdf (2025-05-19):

## Focus Dial — a Digital Distraction Blocker

By salimbenbouz (https://www.instructables.com/member/salimbenbouz/) in Circuits (https://www.instructables.com/circuits/)Gadgets (https://www.instructables.com/circuits/gadgets/projects/)

## Introduction: Focus Dial — a Digital Distraction Blocker

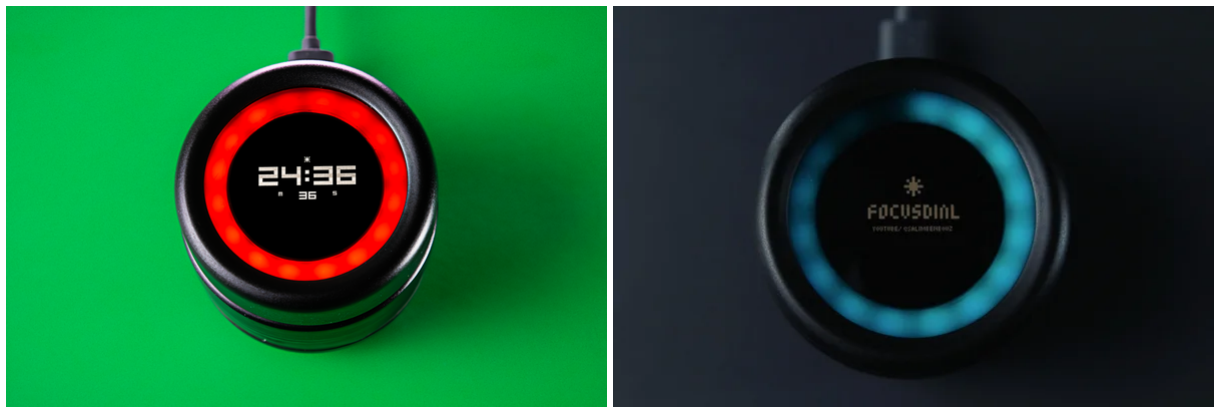
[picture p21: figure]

Tired of constant distractions, I built the Focus Dial (https://github.com/sb-ocr/focus-dial)—my take on the failed TimeChi crowdfunding project. It helps me work in time blocks by activating a Do Not Disturb mode on my phone and (https://www.indiegogo.com/projects/timechi-your-smart-productivity-tool#/) integrates with Home Assistant via webhook triggers to set lighting scenes and block distracting apps at the network level during focus sessions.

## Supplies

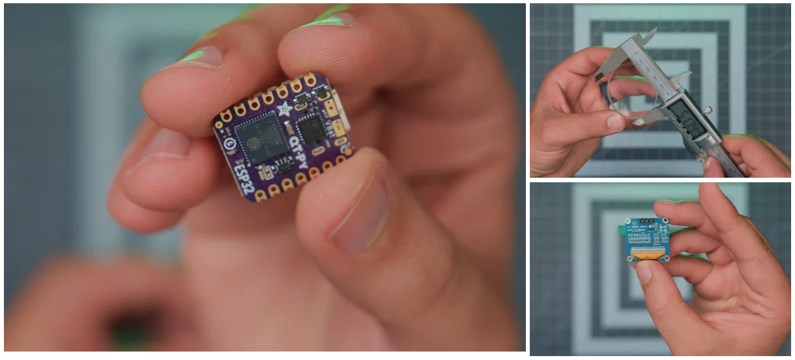
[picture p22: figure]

Bill of materials

1. Adafruit QT Py ESP32 Pico Adafruit (https://www.adafruit.com/product/5395)
2. NeoPixel Ring - 16 x 5050 Adafruit (https://www.adafruit.com/product/1463)
3. OLED Module 128x64 White SSD1306 Amazon (https://geni.us/bmP3j6U)
4. Low Profile 56mm Encoder Digikey (https://www.digikey.ca/en/products/detail/bourns-inc/PER561-P115-N0015/13999552)
5. 12mm Tactile Push Button Amazon (https://geni.us/iDwJiM)
6. Hook-up wire Amazon (https://geni.us/3zM5X)
7. Heat shrink tubing Amazon (https://geni.us/RlvPl)
8. 50 mm Diameter Beaker Cover Amazon (https://geni.us/cs1De)
9. M2 Self-Tapping Screws Assortment Amazon (https://geni.us/TI1rw)
10. Roller Bearings with Washers 30mm Bore 47mm Amazon (https://geni.us/OI3yaX)
11. Rubber Feet Amazon (https://geni.us/v9UIrL)
12. Tint Film (Black) Amazon (https://geni.us/i7Yn6YZ)
13. Rust-oleum Matte Clear Amazon (https://geni.us/GUnWYG)
14. Silicone Mold Making Rubber Amazon (https://geni.us/8sKgkH)
15. Titanium Dioxide Pigment Amazon (https://geni.us/1yc8M)

Tools

1. FDM 3D Printer Bambu Lab A1 (https://bit.ly/4gwNFhK)
2. Resin Printing System Heygears (https://bit.ly/heygears-reflex)
3. Soldering Station/Iron. Amazon (https://geni.us/16zcw5)
4. Helping hands Amazon (https://geni.us/qmbA3W)
5. Precision Screwdriver Set Amazon (https://geni.us/pE8dvKd)
6. Wire stripper Amazon (https://geni.us/ujTOmu)
7. Sanding Sponges Amazon (https://geni.us/QMGA)
8. Flux, Solder

9. Sandpaper Assortment
10. Flush cutters
11. Tweezers, pliers

Affiliate links may be included in this list. I may receive a small commission at no additional cost to you.

## Step 1: Watch the Build Video

In the project video, (https://youtu.be/nZa-Vqu-_fU) I walk you through the entire process of designing and building this. Watching it will provide an understanding of each step and how all the components fit together.

## Step 2: Fabrication

You can download the STL files (https://github.com/sb-ocr/focus-dial/tree/main/cad/STLs) from the GitHub repository (https://github.com/sb-ocr/focus-dial) or choose your preferred format from the Fusion embed. (https://a360.co/4iVXBTw)

Begin by 3D printing the enclosure parts. For the final version, I used a resin printer (Heygears Reflex), but these parts can also be printed on a high-quality FDM 3D printer (https://bit.ly/4gwNFhK) with some adjustments. You might need to tweak the thin wall surrounding the encoder and bottom piece for better results.

If you decide not to make the diffuser out of silicone rubber like in the video, (https://youtu.be/nZa-Vqu-_fU?si=FJJZqmHCFqQJz7bt&t=620) now is a good time to 3D print it.

Focus Dial (https://a360.co/4iVXBTw)

## Step 3: Post-processing

After printing the parts, I smoothed the visible surfaces using a 1000-grit foam sanding strip. (https://geni.us/QMGA) The resin print is already about 80% of the finish, so the sanding was minimal. If you opt for the FDM route and want a similarly smooth finish, check out this project (https://www.instructables.com/Making-a-Retro-Inspired-Raspberry-Pi-Enclosure-por/#step3) that covers finishing techniques for FDM prints.

Once sanding was complete, I washed the parts with soap and water and let them to air dry in preparation for the clear coat. I used a matte clear spray (Rust-Oleum) and applied it in thin, even coats. Be sure to follow the drying and curing instructions provided on the can for the best results.

## Step 4: Diffuser

As mentioned in the video, (https://youtu.be/nZa-Vqu-_fU?si=FJJZqmHCFqQJz7bt&t=620) I 3D-printed a mold to create a diffuser using two-part silicone (https://geni.us/8sKgkH) and a small amount of titanium dioxide. (https://geni.us/1yc8M) You only need a tiny amount in the mix to achieve a diffused look.

I let the silicone cure for 6 hours before carefully demolding it from the 3D-printed.

## Step 5: Glass Lens

Next, I applied the tint film (https://geni.us/i7Yn6YZ) to the inside on the lens, trying to avoid creating any bubbles. I left the film oversized until most of it was applied, then used a hobby knife to carefully trace around and remove the excess.

For stubborn edges, applying a bit of heat can help secure them. Once the film was in place, I carefully removed the second transparent protective layer and set it aside for later.

## Step 6: Assembly _1

To begin the assembly, I first got rid of the pins from the OLED module and trimmed the four corners to about 45° with flush cutters to ensure it fit into the face piece. (https://github.com/sb-ocr/focus-dial/blob/main/cad/STLs/Face.stl) Next, I soldered four thin-gauge wires to the pads on the module and positioned it in place.

I then added a backing piece (https://github.com/sb-ocr/focus-dial/blob/main/cad/STLs/Screen%20Backing.stl) to the OLED and used black electrical tape to secure it. The tape also helps reduce light bleed from the back of the screen.

Next, I installed the LED ring into the face piece (https://github.com/sb-ocr/focus-dial/blob/main/cad/STLs/Face.stl) (as shown in the picture) and soldered slightly thicker wires for the power. The wire bundle can then be threaded through the central shaft. (https://github.com/sb-ocr/focus-dial/blob/main/cad/STLs/Central%20Shaft.stl) Finally, I secured the shaft (https://github.com/sb-ocr/focus-dial/blob/main/cad/STLs/Central%20Shaft.stl) to the face piece (https://github.com/sb-ocr/focus-dial/blob/main/cad/STLs/Face.stl) using six (M2 x 4-5mm) self-tapping screws.

## Step 7: Assembly _2

To prepare the encoder for the enclosure, I removed the ground leads and bent the three pins closer to the encoder body. Then, I soldered three wires to the pins and insulated them with heat shrink tubing.

Next, I threaded the three wires through the opening indicated by the arrow in the picture and snapped the encoder into place. (https://github.com/sb-ocr/focus-dial/blob/main/cad/STLs/Encoder%20Bottom.stl) After that, I added the central ring (https://github.com/sb-ocr/focus-dial/blob/main/cad/STLs/Central%20Ring.stl) and bearings, (https://geni.us/OI3yaX) securing the entire assembly to the previously assembled face piece using five (M2 x 10mm) self-tapping screws.

Be careful not to overtighten this part, as it could block the bearings from moving. Adjust the screws until you achieve a secure assembly with smooth rotation of the central ring. (https://github.com/sb-ocr/focus-dial/blob/main/cad/STLs/Central%20Ring.stl)

## Step 8: Assembly _3

I used two small pieces of double-sided tape to secure the ESP32 in place for soldering. On the right side, I soldered the power wires, while on the left side, I connected the data wires for the LED ring, encoder, and button. For detailed connections, please refer to the wiring diagram.

One important note: I didn’t leave a comfortable amount of space for the wires. The cables need to route over the three circles, staying as neat and flat as possible.

Next, I soldered two wires to the button, positioned it on the small platform, (https://github.com/sb-ocr/focus-dial/blob/main/cad/STLs/Button%20Holder.stl) and used it to divide the cables, keeping the wiring tidy.

The button cap (https://github.com/sb-ocr/focus-dial/blob/main/cad/STLs/Button%20Cap.stl) serves two purposes: it prevents the button from falling out and covers the wires to avoid accidental snags. After placing the button cap, (https://github.com/sb-ocr/focus-dial/blob/main/cad/STLs/Button%20Cap.stl) I secured it to the assembly using three (M2 x 4-5mm) self-tapping screws.

## Step 9: Assembly _4

To finish the assembly, I added three compression springs (approximately 6 x 10 mm) on the 3 screws in the button cap. (https://github.com/sb-ocr/focus-dial/blob/main/cad/STLs/Button%20Cap.stl) Next, I placed the bottom button (https://github.com/sb-ocr/focus-dial/blob/main/cad/STLs/Bottom%20Button.stl) and bottom piece, (https://github.com/sb-ocr/focus-dial/blob/main/cad/STLs/Bottom.stl) securing them with four (M2 x 8mm) self-tapping screws. Ensure the orientation is correct by referring to the images.

The final step is to position the diffuser in its designated channel and place the lens on top. Once aligned, secure the bezel (https://github.com/sb-ocr/focus-dial/blob/main/cad/STLs/Bezel.stl) tightly to complete the assembly.

## Step 10: Firmware

Set Up the IDE

1. VS Code:
2. If you don’t already have it, download and install Visual Studio Code. (https://code.visualstudio.com/)
3. PlatformIO:
4. Open VS Code.
5. Go to the Extensions Marketplace (Ctrl+Shift+X or Cmd+Shift+X).
6. Search for "PlatformIO" and install it if it’s not already installed.
7. Python:
8. Ensure Python 3.6+ is installed on your system. If not, download it from python.org and add it to your system's PATH.
9. Install Drivers (if needed):
10. On Windows, you may need USB drivers for the ESP32 Pico QT Py to be recognized.
11. Download and install the drivers from Adafruit's Drivers Page. (https://learn.adafruit.com/adafruit-qt-py-esp32-pico/arduino-ide-setup)

Build and Upload the Firmware

1. Clone or Download the Repository:
2. Clone the repo from GitHub (https://github.com/sb-ocr/focus-dial)
3. Or download the project as a ZIP and extract it.
4. Open the Project in VS Code:
5. In VS Code, go to File > Open Folder... and select the project folder.
6. Connect the Focus Dial to your computer with a data-capable USB cable.
7. Select the Serial Port:
8. Open the PlatformIO toolbar in VS Code.
9. Choose the serial port for your board from the drop-down menu.
10. Build and Upload:
11. Click Build to compile the firmware.
12. Click Upload to flash the firmware to the board.

After the build and upload, you should see success messages confirming the firmware was built and flashed. The Focus dial will now display a splash screen with a spinner LED animation. If you see this, everything is working correctly!

If you need to adjust pins assignments or other variables you can change them in firmware/include/Config.h (https://github.com/sb-ocr/focus-dial/blob/main/firmware/include/Config.h) and build/upload again.

## Step 11: Usage

After the splash screen, the device will boot for the first time and greet you with the provisioning screen. In this mode, the ESP runs as an access point (AP), serving a webpage where you can configure the Wi-Fi credentials, set the webhook URL for your home automation trigger, and pair the device with your phone via Bluetooth for the janky personal automation trigger for IOS.

Note: Setting up Home Assistant and automation triggers is beyond the scope of this guide, but you can find some documentation linked here. (https://www.home-assistant.io/docs/automation/trigger/#webhook-trigger)

Once provisioning is complete, the device transitions to the main screen, indicated by a blue breathing animation. To start a session, click the central button once or use the encoder to adjust the session duration.

When the timer starts, the device sends a "start" payload to the webhook task. To pause the timer, click the button once while it’s running. To cancel the timer, click the button twice. When the timer runs out, the device sends a "stop" payload to complete the session.

To reset the device and re-trigger the provisioning process, hold down the main button for a few seconds while in the idle state.

## Step 12: Done

That's it for this one you're done! Thank you for sticking around until the end.

I have other ideas and I plan on making projects like these Follow me (https://linktr.ee/salimbenbouz) for more.

Youtube /@salimbenbouz (https://www.youtube.com/@salimbenbouz)

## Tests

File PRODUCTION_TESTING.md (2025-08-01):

# Production Testing Guide for Timer Device

This guide outlines the quality control process for manufacturing the ESP32-S3-Touch-AMOLED-1.75 timer devices.

## Overview

The firmware includes a built-in test framework that can be enabled during compilation. This allows you to thoroughly test each device during production without needing separate test firmware.

## Production Workflow

### Step 1: Assemble Hardware
- Complete physical assembly of the timer device
- Ensure all components are properly connected

### Step 2: Compile and Upload Test Firmware

```bash
# Navigate to firmware directory
cd /Users/Travis/Developer/ProjectTimerDevice/firmware

# Compile firmware with TEST_MODE enabled
arduino-cli compile --fqbn esp32:esp32:esp32s3:USBMode=hwcdc,FlashSize=16M,PartitionScheme=huge_app --build-property "build.psram_type=opi" --build-property "compiler.cpp.extra_flags=-DTEST_MODE" --clean

# Upload to device (adjust port as needed)
arduino-cli upload -p /dev/cu.usbmodem32301 --fqbn esp32:esp32:esp32s3:USBMode=hwcdc,FlashSize=16M,PartitionScheme=huge_app
```

### Step 3: Run Quality Control Tests

1. **Open Serial Monitor**:
   ```bash
   # Reset device and monitor
   esptool.py --port /dev/cu.usbmodem32301 read_mac >/dev/null 2>&1 && sleep 0.5 && timeout 30 cat /dev/cu.usbmodem32301
   ```

2. **Run Test Suite**:
   - Wait for device to boot (you'll see "TEST MODE ENABLED")
   - Type `test` and press Enter
   - Tests will run automatically

3. **Verify Results**:
   - All tests should show ✓ PASS
   - Note any failures for troubleshooting
   - Basic test suite takes ~5 minutes

4. **Optional: Run Extended Tests**:
   - Type `stress` for 4-hour continuous operation test
   - Only needed for first device in batch or after design changes

### Step 4: Flash Production Firmware

```bash
# Compile firmware WITHOUT TEST_MODE (production version)
arduino-cli compile --fqbn esp32:esp32:esp32s3:USBMode=hwcdc,FlashSize=16M,PartitionScheme=huge_app --build-property "build.psram_type=opi" --clean

# Upload production firmware
arduino-cli upload -p /dev/cu.usbmodem32301 --fqbn esp32:esp32:esp32s3:USBMode=hwcdc,FlashSize=16M,PartitionScheme=huge_app

# Optional: Upload web interface
./mklittlefs/mklittlefs -c data -b 4096 -p 256 -s 0x91E000 littlefs_current.bin
esptool.py --chip esp32s3 --port /dev/cu.usbmodem32301 --baud 921600 write_flash 0x6E2000 littlefs_current.bin
```

### Step 5: Final Verification

```bash
# Monitor startup to ensure production firmware works
esptool.py --port /dev/cu.usbmodem32301 read_mac >/dev/null 2>&1 && sleep 0.5 && timeout 20 cat /dev/cu.usbmodem32301
```

- Verify device starts normally
- Check "Integration Testing Available" message (NOT "TEST MODE ENABLED")
- Device is ready for packaging

### Step 6: Package for Shipping
- Device now has production firmware
- No test code included in shipped product
- Ready for customer use

## Test Coverage

### Basic Tests (Always Run)
- Math operations and memory allocation
- String handling
- Basic functionality verification

### Hardware Tests (When Enabled)
- **Display**: Pattern rendering
- **Touch**: Touch detection and response
- **Encoder**: Rotation and button press
- **LED**: NeoPixel color cycling
- **RTC**: Time keeping accuracy
- **WiFi**: Connection capability
- **Power**: Battery and charging status
- **Memory**: PSRAM availability

### Continuous Operation Test (Optional)
- 4+ hour stress test
- Random state transitions
- Memory leak detection
- Stability verification

## Common Issues

### Port Not Found
```bash
# List available ports
ls /dev/cu.* | grep -E "(usbmodem|wchusbserial)"
```

### Device Won't Wake from Sleep
```bash
# Force wake with esptool
esptool.py --port /dev/cu.usbmodem32301 --before default_reset --after hard_reset chip_id
```

### Compilation Errors
- Ensure you're in the firmware directory
- Check that all libraries are installed
- Use `--clean` flag to force fresh compilation

## Important Notes

1. **Flash Size**: This device has 16MB flash (not default 4MB) - the commands above include the correct `FlashSize=16M` parameter
2. **Partition Scheme**: Uses `huge_app` partition for the 2MB firmware
3. **Test Mode**: Only enabled during production testing, never shipped to customers
4. **Web Interface**: The `littlefs_current.bin` contains the web interface accessible at http://thetimer.local

## Quick Reference Card

```bash
# Test Mode Compile & Upload
arduino-cli compile --fqbn esp32:esp32:esp32s3:USBMode=hwcdc,FlashSize=16M,PartitionScheme=huge_app --build-property "build.psram_type=opi" --build-property "compiler.cpp.extra_flags=-DTEST_MODE" --clean && arduino-cli upload -p /dev/cu.usbmodem32301 --fqbn esp32:esp32:esp32s3:USBMode=hwcdc,FlashSize=16M,PartitionScheme=huge_app

# Production Compile & Upload  
arduino-cli compile --fqbn esp32:esp32:esp32s3:USBMode=hwcdc,FlashSize=16M,PartitionScheme=huge_app --build-property "build.psram_type=opi" --clean && arduino-cli upload -p /dev/cu.usbmodem32301 --fqbn esp32:esp32:esp32s3:USBMode=hwcdc,FlashSize=16M,PartitionScheme=huge_app

# Monitor Serial Output
esptool.py --port /dev/cu.usbmodem32301 read_mac >/dev/null 2>&1 && sleep 0.5 && timeout 30 cat /dev/cu.usbmodem32301
```

## Production Checklist

- [ ] Hardware assembled correctly
- [ ] Test firmware uploaded
- [ ] All tests PASS
- [ ] Production firmware uploaded  
- [ ] Final boot verification
- [ ] Web interface uploaded (if needed)
- [ ] Device packaged for shipping

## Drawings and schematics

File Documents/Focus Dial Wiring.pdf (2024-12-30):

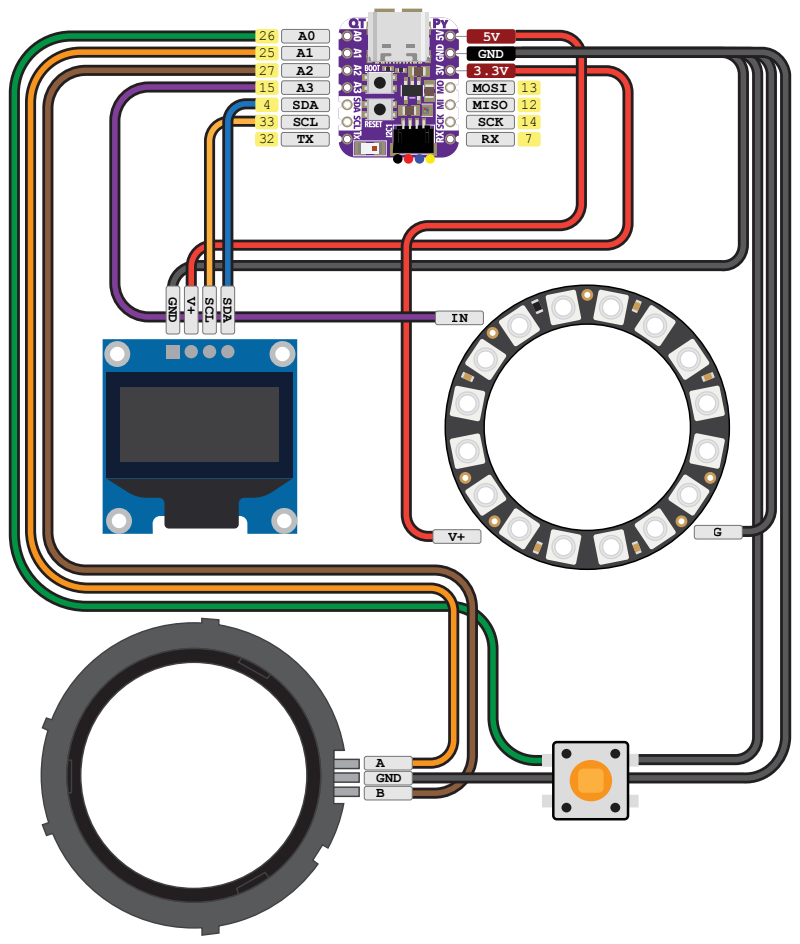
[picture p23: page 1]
33 SCL; 25 A1 27 A2 15 A3 4 SDA; GND 3.3V MOSI 13 MISO 12 SCK 14; GND; V+ SCL; SDA; A GND B

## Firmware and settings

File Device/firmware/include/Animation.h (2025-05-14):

#pragma once

#include <Adafruit_GFX.h>
// #include <Adafruit_SSD1306.h> // Temporarily commented out for LVGL migration - Phase 1

#define DEFAULT_FRAME_WIDTH 48
#define DEFAULT_FRAME_HEIGHT 48
#define DEFAULT_FRAME_DELAY 42

class Animation
{
public:
    // Animation(Adafruit_SSD1306 *display); // Temporarily modified for LVGL migration - Phase 1
    Animation(); // Temporarily modified for LVGL migration - Phase 1
    void start(const byte *frames, int frameCount, bool loop, bool reverse, unsigned long durationMs, int width, int height); // Moved reverse parameter
    void update();
    bool isRunning();

private:
    // Adafruit_SSD1306 *oled; // Temporarily commented out for LVGL migration - Phase 1
    const byte *animationFrames;
    int totalFrames;
    int currentFrame;
    int frameWidth;
    int frameHeight;
    int frameX;
    int frameY;
    bool animationRunning;
    bool loopAnimation;
    bool playInReverse;
    unsigned long animationStartTime;
    unsigned long lastFrameTime;
    unsigned long animationDuration;
    unsigned long frameDelay;
};

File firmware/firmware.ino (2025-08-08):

/**
 * Timer Arduino - Smooth Scrolling Demo
 * Three black screens with centered text
 * For ESP32-S3-Touch-AMOLED-1.75
 */

#include <Arduino.h>
#include <Wire.h>
#include <lvgl.h>
#include <string.h>
#include "Arduino_GFX_Library.h"
#include "HWCDC.h"
#include "XPowersLib.h"
// #include <ESP_IOExpander_Library.h> // Disabled due to I2C driver conflict
#include <esp_sleep.h>
#include <driver/rtc_io.h>
#include <driver/gpio.h>
#include <esp_task_wdt.h>
#include <WiFi.h>
#include <WebServer.h>
// #include <WebSocketsServer.h>
#include <ArduinoJson.h>
#include <LittleFS.h>
#include <ESPmDNS.h>
#include <time.h>
#include "SensorPCF85063.hpp"

// State Machine
#include "src/state_machine/include/StateMachine.h"
#include "src/state_machine/states/SleepState.h"
#include "src/state_machine/include/LEDController.h"
#include "src/state_machine/states/TimerState.h"
#include "src/state_machine/states/ProjectSelectState.h"

// UI
#include "src/ui/ScreenManager.h"
#include "src/ui/UIEventHandler.h"
#include "src/ui/TouchManager.h"
#include "src/ProjectManager.h"

// Simple Encoder
#include "src/SimpleEncoder.h"

// Production Test
#include "src/SimpleProductionTest.h"

// Audio System
#include "src/audio/AlarmController.h"

// Pin Configuration
#include "pin_config.h"

// File System
#include <FS.h>

// RTC Configuration
SensorPCF85063 rtc;
bool rtcInitialized = false;

// NTP Configuration
const char* ntpServer = "pool.ntp.org";
const long gmtOffset_sec = -8 * 3600;  // PST (UTC-8) - adjust for your timezone
const int daylightOffset_sec = 3600;   // 1 hour for DST

// Declare custom fonts
LV_FONT_DECLARE(lv_font_roboto_mono_120);
LV_FONT_DECLARE(lv_font_barlow_24);
LV_FONT_DECLARE(lv_font_barlow_bold_48);

// Color definitions for consistent styling
#define COLOR_FOREGROUND lv_color_hex(0xDDDDDD)  // Main text color - brightest
#define COLOR_BACKGROUND lv_color_hex(0x888888)  // Secondary elements - much dimmer

// USB Serial for ESP32-S3
HWCDC USBSerial;

// Power Management
XPowersAXP2101 power;

// Power button management
bool pmu_flag = false;
// Sleep functionality disabled - was causing stack overflow
// unsigned long last_activity_time = 0;
// const unsigned long INACTIVITY_TIMEOUT = 180000; // 3 minutes
bool is_sleeping = false;  // Keep for now to avoid breaking other code
// bool is_waking_up = false;
// unsigned long wake_time = 0;
// const unsigned long MIN_AWAKE_TIME = 2000;

// Wake-up configuration
#define WAKE_BUTTON_PIN GPIO_NUM_0  // BOOT button as wake source
#define PMU_IRQ_PIN GPIO_NUM_6      // AXP2101 IRQ pin (potentially direct connection)

// External Sleep/Wake Button
volatile bool externalButtonPressed = false;
unsigned long lastExternalButtonPress = 0;

RTC_DATA_ATTR int bootCount = 0;   // RTC memory variable to track boot count

// Display Configuration
#define LCD_SDIO0 4
#define LCD_SDIO1 5
#define LCD_SDIO2 6
#define LCD_SDIO3 7
#define LCD_SCLK 38
#define LCD_CS 12
#define LCD_RESET 39
#define LCD_WIDTH 466
#define LCD_HEIGHT 466

// Touch Configuration
#define IIC_SDA 15
#define IIC_SCL 14
#define TP_INT 11
#define TP_RESET 40

// LVGL Configuration
#define LVGL_TICK_PERIOD_MS 2  // 2ms as per working example

// Display objects
Arduino_DataBus *bus = new Arduino_ESP32QSPI(
    LCD_CS, LCD_SCLK, LCD_SDIO0, LCD_SDIO1,
    LCD_SDIO2, LCD_SDIO3);

Arduino_GFX *gfx = new Arduino_CO5300(
    bus,
    LCD_RESET,
    0,     // rotation
    false, // IPS
    LCD_WIDTH,
    LCD_HEIGHT,
    6,     // col_offset1
    0,     // row_offset1
    0,     // col_offset2
    0      // row_offset2
);

// Global pointer for ScreenManager to access display
void* gfx_ptr = gfx;

// LVGL variables
static lv_disp_draw_buf_t draw_buf;
static lv_color_t *buf1 = NULL;
static lv_color_t *buf2 = NULL;

// Screen objects
static lv_obj_t *screen1;
static lv_obj_t *screen2;
static lv_obj_t *screen3;
static lv_obj_t *label1;
static lv_obj_t *label2;
static lv_obj_t *label3;

// Timer display elements
static lv_obj_t *minutes_label;
static lv_obj_t *seconds_label;
static lv_obj_t *date_label;

// Screen management
static uint8_t current_screen = 0;
static bool transitioning = false;

// Animation types - simplified to fade only
typedef enum {
    TRANS_FADE
} transition_type_t;

// Global screen manager instance
ScreenManager screenManager;
TouchManager touchManager;

// Touch handling
#include "TouchDrvCSTXXX.hpp"
TouchDrvCSTXXX touch;
int16_t touch_x[5], touch_y[5];

// Simple debounce for touch
unsigned long lastTouchTime = 0;
const unsigned long TOUCH_DEBOUNCE_MS = 50; // 50ms debounce

// Global input device handle for touch management
lv_indev_t * touch_indev = NULL;

// Track if we're in a touch sequence
bool touchSequenceActive = false;
unsigned long touchSequenceStartTime = 0;

// Forward declarations
void go_to_next_screen();
void go_to_prev_screen();
void setPMUFlag(void);
void goToSleep(bool deep_sleep = false);
void resetActivityTimer();
void handleWakeUp();
void IRAM_ATTR onExternalButtonPress();

// Web Server
WebServer apiServer(80);
// WebSocketsServer webSocket(81);
bool webServerRunning = false;

void startWebServer();
void handleApiProjects();
void handleApiStatus();
void handleApiProjectsPost();
void handleApiUpdateProject();
void handleApiDeleteProject();
void handleApiWebhookGet();
void handleApiWebhookPost();
void handleApiKeyGet();
void handleApiKeyPost();
void handleNotFound();
void handleApiColorPreview();
void handleApiColorReset();
void handleApiAlarmSounds();
void handleApiAlarmSettingsGet();
void handleApiAlarmSettingsPost();
void handleApiAlarmPreview();
void handleApiAlarmStop();
void syncTimeFromNTP();
void updateDateTimeDisplay();


// Rounder callback for display optimization (critical for performance)
void display_rounder_cb(struct _lv_disp_drv_t *disp_drv, lv_area_t *area) {
    // Ensure x1 and y1 are even
    if(area->x1 % 2 != 0) area->x1--;
    if(area->y1 % 2 != 0) area->y1--;
    // Ensure x2 and y2 are odd
    if(area->x2 % 2 == 0) area->x2++;
    if(area->y2 % 2 == 0) area->y2++;
}

// Display flush callback
void display_flush(lv_disp_drv_t *disp, const lv_area_t *area, lv_color_t *color_p) {
    uint32_t w = (area->x2 - area->x1 + 1);
    uint32_t h = (area->y2 - area->y1 + 1);

#if (LV_COLOR_16_SWAP != 0)
    gfx->draw16bitBeRGBBitmap(area->x1, area->y1, (uint16_t *)&color_p->full, w, h);
#else
    gfx->draw16bitRGBBitmap(area->x1, area->y1, (uint16_t *)&color_p->full, w, h);
#endif

    lv_disp_flush_ready(disp);
}

// Touch read callback - now uses TouchManager for release-only processing
void touchpad_read(lv_indev_drv_t *indev_driver, lv_indev_data_t *data) {
    static int16_t last_x = 0, last_y = 0;
    unsigned long now = millis();
    
    // Simple debounce
    if (now - lastTouchTime < TOUCH_DEBOUNCE_MS) {
        data->state = LV_INDEV_STATE_REL;
        return;
    }
    
    // Read touch directly
    uint8_t touch_count = touch.getPoint(touch_x, touch_y, touch.getSupportTouchPoint());
    
    bool touchDetected = (touch_count > 0);
    if (touchDetected) {
        last_x = touch_x[0];
        last_y = touch_y[0];
        lastTouchTime = now;
    }
    
    // Process touch through TouchManager (handles all logic)
    touchManager.processTouch(touchDetected, last_x, last_y);
    
    // Always report release to LVGL - we don't want LVGL processing any events
    data->state = LV_INDEV_STATE_REL;
    data->point.x = last_x;
    data->point.y = last_y;
}

// LVGL tick function
void lv_tick_task(void *arg) {
    lv_tick_inc(LVGL_TICK_PERIOD_MS);
}

// Screen transition with fade animation only
void transition_to_screen(lv_obj_t *new_screen, uint32_t duration) {
    if (transitioning) return;  // Prevent overlapping transitions
    
    transitioning = true;
    
    USBSerial.println("Transitioning to screen with fade animation");
    
    lv_scr_load_anim(new_screen, LV_SCR_LOAD_ANIM_FADE_IN, duration, 0, false);
    
    // Reset transition flag after animation completes
    lv_timer_t *timer = lv_timer_create([](lv_timer_t *t) {
        transitioning = false;
        lv_timer_del(t);
    }, duration + 50, NULL);
}


// Navigate to next screen
void go_to_next_screen() {
    current_screen = (current_screen + 1) % 3;
    lv_obj_t *target = (current_screen == 0) ? screen1 : (current_screen == 1) ? screen2 : screen3;
    transition_to_screen(target, 500);  // 500ms fade duration
}

// Navigate to previous screen
void go_to_prev_screen() {
    current_screen = (current_screen + 2) % 3;  // +2 is same as -1 with wrap
    lv_obj_t *target = (current_screen == 0) ? screen1 : (current_screen == 1) ? screen2 : screen3;
    transition_to_screen(target, 500);  // 500ms fade duration
}


// Create the screens using the screen manager
void create_screens() {
    // Initialize the screen manager
    screenManager.init();
}

// PMU interrupt flag setter
void setPMUFlag(void) {
    pmu_flag = true;
}

// Reset the inactivity timer - DISABLED
void resetActivityTimer() {
    // Function disabled - was causing stack overflow
}

// Enter sleep mode - DISABLED
void goToSleep(bool deep_sleep) {
    // Function disabled - was causing issues
    return;
    
    if (deep_sleep) {
        USBSerial.println("Entering DEEP sleep mode (power button pressed)...");
    } else {
        USBSerial.println("Entering light sleep mode (inactivity)...");
    }
    USBSerial.flush();
    delay(10); // Allow serial to flush
    
    is_sleeping = true;
    
    // Turn off display backlight gradually
    for (int i = 200; i >= 0; i -= 5) {
        gfx->Display_Brightness(i);
        delay(10);
    }
    
    if (deep_sleep) {
        // Deep sleep configuration - only BOOT button can wake
        // Configure wake-up source - BOOT button only
        esp_sleep_enable_ext0_wakeup(WAKE_BUTTON_PIN, 0); // Wake on LOW
        
        // Note: Touch wake NOT enabled for deep sleep
        USBSerial.println("Deep sleep: Only BOOT button can wake!");
        USBSerial.flush();
        delay(10);
        
        // Enter deep sleep - ESP32 will restart on wake
        esp_deep_sleep_start();
        // Code never reaches here
    } else {
        // Light sleep configuration - ONLY touch wake enabled
        // Clear any PMU interrupts
        power.clearIrqStatus();
        
        // Configure wake-up sources for light sleep
        // Touch pin wake-up ONLY
        gpio_wakeup_enable(GPIO_NUM_11, GPIO_INTR_LOW_LEVEL);
        esp_sleep_enable_gpio_wakeup();
        
        USBSerial.println("Light sleep: Touch screen to wake!");
        USBSerial.flush();
        delay(10);
        
        // Enter light sleep (keeps RAM, faster wake-up)
        esp_light_sleep_start();
        
        // Code resumes here after wake-up
        handleWakeUp();
    }
}

// Handle wake-up from sleep - DISABLED
void handleWakeUp() {
    // Function disabled
    return;
    
    esp_sleep_wakeup_cause_t wakeup_reason = esp_sleep_get_wakeup_cause();
    
    USBSerial.println("Waking up from light sleep...");
    
    switch(wakeup_reason) {
        case ESP_SLEEP_WAKEUP_GPIO:
            USBSerial.println("Wake-up from touch screen");
            break;
        default:
            USBSerial.println("Wake-up from unknown source");
            break;
    }
    
    // Clear any pending interrupts
    power.clearIrqStatus();
    
    // Restore display brightness
    for (int i = 0; i <= 200; i += 5) {
        gfx->Display_Brightness(i);
        delay(10);
    }
    
    // Timer reset disabled
    unsigned long current = millis();
    // last_activity_time = current;
    // wake_time = current;
    
    // Restore normal PMU interrupt configuration
    power.disableIRQ(XPOWERS_AXP2101_ALL_IRQ);
    power.enableIRQ(XPOWERS_AXP2101_PKEY_SHORT_IRQ | 
                   XPOWERS_AXP2101_VBUS_INSERT_IRQ | 
                   XPOWERS_AXP2101_VBUS_REMOVE_IRQ |
                   XPOWERS_AXP2101_BAT_CHG_START_IRQ |
                   XPOWERS_AXP2101_BAT_CHG_DONE_IRQ);
    
    USBSerial.print("System resumed from light sleep - timers reset to: ");
    USBSerial.println(current);
}

// External button interrupt handler - keep ISR minimal (no millis or heavy ops)
void IRAM_ATTR onExternalButtonPress() {
    externalButtonPressed = true;
}
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
void loop() {
    // Reset watchdog timer at the start of each loop
    esp_task_wdt_reset();
    
    // Check for test mode command
    if (USBSerial.available()) {
        String command = USBSerial.readString();
        command.trim();
        USBSerial.print("Received command: '");
        USBSerial.print(command);
        USBSerial.println("'");
        if (command.equalsIgnoreCase("TEST") || command.equalsIgnoreCase("test")) {
            // Reset watchdog before test
            esp_task_wdt_reset();
            
            // Run the test
            SimpleProductionTest::runTest();
            
            // Extra safety after test
            esp_task_wdt_reset();
            delay(100);
        }
        else if (command.equalsIgnoreCase("SLEEP") || command.equalsIgnoreCase("sleep")) {
            USBSerial.println("=== MANUAL SLEEP COMMAND ===");
            USBSerial.println("Transitioning to light sleep immediately (inactivity mode)...");
            // Get the sleep state and configure it for inactivity mode (light sleep)
            SleepState* sleepState = stateMachine.sleepState;
            if (sleepState) {
                sleepState->setDeepSleep(false); // Use light sleep for inactivity timeout
                // Transition to sleep state
                stateMachine.changeState(sleepState);
            }
        }
        else if (command.equalsIgnoreCase("CLEARWIFI") || command.equalsIgnoreCase("clearwifi")) {
            USBSerial.println("=== CLEARING WIFI CREDENTIALS ===");
            Preferences preferences;
            preferences.begin("wifi", false);
            preferences.clear();
            preferences.end();
            USBSerial.println("WiFi credentials cleared!");
            USBSerial.println("Restarting device...");
            delay(1000);
            ESP.restart();
        }
        else if (command.equalsIgnoreCase("STAYAWAKE") || command.equalsIgnoreCase("stayawake")) {
            USBSerial.println("=== STAY AWAKE MODE ACTIVATED ===");
            // Note: Inactivity timeout is currently disabled in firmware
            // This command is a placeholder for when it's re-enabled
            USBSerial.println("Note: Inactivity timeout is currently disabled in this firmware version");
            USBSerial.println("Device will only sleep when power button is pressed");
        }
    }
    
    // Skip the entire loop if sleeping
    if (is_sleeping) {
        return;
    }
    
    // Update state machine
    stateMachine.update();
    
    // Handle encoder input for confirmation dialog
    if (screenManager.isConfirmDialogVisible()) {
        int delta = simpleEncoder.readDelta();
        if (delta != 0) {
            bool currentSelection = screenManager.getConfirmSelection();
            screenManager.updateConfirmSelection(!currentSelection); // Toggle selection
            USBSerial.print("Confirmation dialog encoder: switched to ");
            USBSerial.println(screenManager.getConfirmSelection() ? "YES" : "NO");
        }
    }
    
    // Sync LVGL display with state machine state
    static const char* lastStateName = "";
    State* currentState = stateMachine.getCurrentState();
    if (currentState) {
        const char* stateName = currentState->getStateName();
        if (strcmp(stateName, lastStateName) != 0) {
            // State changed - update display
            USBSerial.print("State changed to: ");
            USBSerial.println(stateName);
            
            if (strcmp(stateName, "IdleState") == 0) {
                screenManager.showIdleScreen();
                // Update the idle screen with the current duration (duration is in seconds)
                int durationSeconds = stateMachine.getPendingDuration();
                // Display as MM:SS format for timer
                int minutes = durationSeconds / 60;
                int seconds = durationSeconds % 60;
                screenManager.updateIdleTime(minutes, seconds);
                USBSerial.print("Switched to idle screen with duration: ");
                USBSerial.print(durationSeconds);
                USBSerial.println(" seconds");
            } else if (strcmp(stateName, "AdjustState") == 0) {
                int duration = stateMachine.getPendingDuration();
                screenManager.showAdjustScreen(duration);
                USBSerial.println("Switched to adjust screen");
            } else if (strcmp(stateName, "ProjectSelectState") == 0) {
                screenManager.showProjectScreen();
                USBSerial.println("Switched to project screen");
            } else if (strcmp(stateName, "TimerState") == 0) {
                // TODO: Get actual remaining time and progress
                screenManager.showTimerScreen(0, 0.0f);
                // Project name and color are now set inside showTimerScreen
                USBSerial.println("Switched to timer screen");
            } else if (strcmp(stateName, "PausedState") == 0) {
                // Get remaining time and progress from TimerState if available
                TimerState* timerState = static_cast<TimerState*>(stateMachine.timerState);
                int remainingSeconds = 0;
                float progress = 0.0f;
                if (timerState) {
                    remainingSeconds = timerState->getRemainingSeconds();
                    progress = timerState->getProgressPercentage() / 100.0f;
                    USBSerial.print("Paused with remaining: ");
                    USBSerial.print(remainingSeconds);
                    USBSerial.print(" seconds, progress: ");
                    USBSerial.print(progress * 100);
                    USBSerial.println("%");
                }
                screenManager.showPausedScreen(remainingSeconds, progress);
                USBSerial.println("Switched to paused screen");
            } else if (strcmp(stateName, "DoneState") == 0) {
                screenManager.showDoneScreen();
                USBSerial.println("Switched to done screen");
            }
            lastStateName = stateName;
        }
        
        // Update screen content for states that need continuous updates
        if (strcmp(stateName, "AdjustState") == 0) {
            static int lastAdjustDuration = -1;
            int currentDuration = stateMachine.getPendingDuration();
            if (currentDuration != lastAdjustDuration) {
                screenManager.updateAdjustDuration(currentDuration);
                lastAdjustDuration = currentDuration;
            }
        } else if (strcmp(stateName, "TimerState") == 0) {
            // Cast to TimerState to access timer-specific methods
            TimerState* timerState = static_cast<TimerState*>(currentState);
            if (timerState) {
                unsigned long remaining = timerState->getRemainingSeconds();
                float progress = timerState->getProgressPercentage() / 100.0f;
                screenManager.updateTimerProgress(remaining, progress);
            }
        }
    }
    
    static unsigned long last_print = 0;
    static unsigned long last_transition = 0;
    static bool debug_printed = false;
    unsigned long now = millis();
    
    // Sleep tracking disabled - was causing stack overflow
    
    
    // Check for PMU interrupt by polling the PMU directly
    // This is less efficient but avoids I2C driver conflicts
    static unsigned long last_pmu_check = 0;
    if (now - last_pmu_check > 100) { // Check every 100ms
        last_pmu_check = now;
        // Check if there are any pending interrupts
        if (power.isVbusIn()) {
            // Power connected state changed
        }
    }
    
    // Only check power button when NOT sleeping
    if (!is_sleeping) {
        // Get current interrupt status
        uint32_t irq_status = power.getIrqStatus();
        
        if (irq_status != 0) {
            USBSerial.print("PMU IRQ detected: 0x");
            USBSerial.println(irq_status, HEX);
            
            // Handle power button short press
            if (power.isPekeyShortPressIrq()) {
                USBSerial.println("Power button pressed - transitioning to DEEP sleep");
                power.clearIrqStatus();
                
                // Let SleepState handle display power management
                
                SleepState* sleepState = stateMachine.sleepState;
                if (sleepState) {
                    sleepState->setDeepSleep(true); // Deep sleep
                    stateMachine.changeState(sleepState);
                }
            }
            
            // Handle battery status changes for instant battery icon updates
            if (power.isVbusInsertIrq() || power.isVbusRemoveIrq() ||
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

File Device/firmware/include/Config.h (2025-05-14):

#pragma once

#include <Arduino.h>

// --- Hardware ---
// #define OLED_WIDTH 128 // Removed, specific to old display
// #define OLED_HEIGHT 64 // Removed, specific to old display
// #define OLED_ADDR 0x3C // Removed, specific to old display

#define LED_PIN 1 // XIAO D0
// #define NUM_LEDS 16
#define NUM_LEDS 24 // Updated to match project plan and hardware
#define NEOPIXEL_TYPE NEO_GRB + NEO_KHZ800
#define LED_BRIGHTNESS 100

#define ENCODER_A_PIN 43 // XIAO D6
#define ENCODER_B_PIN 8  // XIAO D9
// #define BUTTON_PIN 26 // Deprecated, replaced by touch

// --- LED Colors (prefixed with FD_ to avoid library conflicts) --
#define FD_BLACK 0x000000
#define FD_RED 0xFF0000
#define FD_GREEN 0x00FF00
#define FD_YELLOW 0xFFFF00
#define FD_BLUE 0x0000FF
#define FD_MAGENTA 0xFF00FF
#define FD_CYAN 0x00FFFF
#define FD_WHITE 0xFFFFFF
#define FD_ORANGE 0xFFA500
#define FD_PURPLE 0x800080
#define FD_PINK 0xFFC0CB
#define FD_TEAL 0x008080
#define FD_LIME 0x00FF00 // Same as GREEN, can be removed if redundant
#define FD_BROWN 0xA52A2A
#define FD_NAVY 0x000080
#define FD_MAROON 0x800000
#define FD_OLIVE 0x808000
#define FD_SILVER 0xC0C0C0
#define FD_GOLD 0xFFD700
#define FD_INDIGO 0x4B0082
#define FD_VIOLET 0xEE82EE
#define FD_TURQUOISE 0x40E0D0
#define FD_SKYBLUE 0x87CEEB
#define FD_SALMON 0xFA8072
#define FD_PLUM 0xDDA0DD
#define FD_KHAKI 0xF0E68C

// Specific Timer Colors
#define FD_COLOR_AMBER 0xFFBF00 // Specific amber color for some states

// --- Defaults ---
#define DEFAULT_TIMER 25 // min - Default to 25 minutes if no value in NVS
#define MIN_TIMER 5      // min - Minimum timer
#define MAX_TIMER 240    // min - Maximum timer (4 hours)

#define SPLASH_DURATION 2 // sec - 2 seconds splash state
#define CHANGE_TIMEOUT 60 // sec - 5 seconds adjust timeout
#define SLEEP_TIMOUT 10   // min - 5 minutes to transition to sleep
#define PAUSE_TIMEOUT 10  // min - 10 minutes to cancel the timer if stayed paused

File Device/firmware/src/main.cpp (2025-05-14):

#include <Arduino.h>
#include "Config.h"
#include "StateMachine.h"
#include "Controllers.h"
#include "managers/ProjectManager.h"
#include "nvs_flash.h" // For NVS - Keep for robust init
#include "nvs.h"       // For NVS - Keep for robust init
#include <lvgl.h>
#include "lv_xiao_round_screen.h"

// Global instances of controllers
// DisplayController displayController(OLED_WIDTH, OLED_HEIGHT, OLED_ADDR); // Commented out, OLED_WIDTH etc removed from Config.h
DisplayController displayController; // Reinstated with parameterless constructor
LEDController ledController(LED_PIN, NUM_LEDS, LED_BRIGHTNESS);
InputController inputController(ENCODER_A_PIN, ENCODER_B_PIN); // BUTTON_PIN removed
NetworkController networkController;
Preferences preferences; // This is the main Preferences object the old firmware uses
ProjectManager projectManager;

// REMOVED NVS Handle and constants for testing (main_nvs_handle, etc.)

// --- Add static function to get the global instance ---
ProjectManager &getProjectManagerInstance()
{
  return projectManager;
}

void setup()
{
  Serial.begin(115200);
  delay(2000); // Delay for serial monitor connection

  Serial.println("--- Main Firmware Booting --- ");

  // --- Robust NVS Flash Initialization (MUST BE DONE FIRST) ---
  esp_err_t nvs_err = nvs_flash_init();
  if (nvs_err == ESP_ERR_NVS_NO_FREE_PAGES || nvs_err == ESP_ERR_NVS_NEW_VERSION_FOUND) {
      Serial.println("NVS: Erasing and re-initializing flash due to no free pages or new version...");
      ESP_ERROR_CHECK(nvs_flash_erase()); // Erase the NVS partition
      nvs_err = nvs_flash_init();        // Retry initialization
  }
  ESP_ERROR_CHECK(nvs_err); // Check the result of the (possibly retried) initialization
  Serial.println("NVS: Flash initialized successfully by main.cpp.");
  // --- End Robust NVS Flash Initialization ---

  // --- LVGL Initialization (Phase 1, Step 1) ---
  lv_init();
#if LVGL_VERSION_MAJOR == 9 // As per MinimalDisplayTest.cpp
  lv_tick_set_cb([](){ return (uint32_t)millis(); });
#endif
  lv_xiao_disp_init();
  lv_xiao_touch_init();
  Serial.println("LVGL, Display, and Touch initialized.");

  // Create a temporary LVGL label
  lv_obj_t *label = lv_label_create(lv_screen_active());
  lv_label_set_text(label, "Main FW LVGL OK");
  lv_obj_align(label, LV_ALIGN_CENTER, 0, 0);
  // --- End LVGL Initialization ---

  // REMOVED the NVS run_counter test block from here.
  // The global 'preferences' object will now be used by other modules (e.g., ProjectManager)
  // which rely on Preferences.begin() internally, and they will benefit from the robust
  // nvs_flash_init() performed above.

  // Initialize Project Manager first (loads data needed by others)
  if (!projectManager.begin()) // Uncommented for Phase 3, Step 1
  {
    Serial.println("FATAL: Failed to initialize Project Manager!");
    // Optional: Enter a safe error state? Loop forever?
    while (1)
    {
      delay(1000);
    }
  }

  // Initialize controllers
  inputController.begin(); // Uncommented for Phase 2, Step 2
  displayController.begin(); // Reinstated, though it's a no-op for now
  ledController.begin();     // Uncommented for Phase 2, Step 1
  ledController.setSolid(FD_GREEN); // Test call for Phase 2, Step 1 - Will be overridden by StartupState
  networkController.begin(); // Uncommented for Phase 3, Step 1

  // Startup state
  stateMachine.begin(); // ADDED: Calls enter() on the initial state (startupState)
}

void loop()
{
  lv_timer_handler();
  stateMachine.update(); // Uncommented for Phase 3, Step 1
  // displayController.updateAnimation(); // Commented out for Phase 1, Step 1

  /* // Temporary encoder test for Phase 2, Step 2 - Commented out as functionality verified
  static long lastEncoderPrintTime = 0;
  if (millis() - lastEncoderPrintTime > 250) { // Print every 250ms
    Serial.print("Encoder Position: ");
    Serial.println(inputController.getEncoderPosition());
    lastEncoderPrintTime = millis();
  }
  */

  delay(5); // Small delay for stability
}

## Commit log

2024-12-27 Enclosure files + firmware
    [Bezel.stl, Bottom Button.stl, Bottom.stl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]
2024-12-30 Wiring diagram + Instructables link
2024-12-31 Fix ESP32-A2DP to version v1.8.5
2025-04-01 fixed led offset issue
    [LedController.cpp]
2025-04-01 Refactor formatting in Config.h and InputController.cpp for improved readability. Adjusted spacing and indentation without altering functionality.
    [Central Ring knurled.stl, Difusser v1.stl, Difusser v2.stl]
2025-04-12 Added projects to track time to
    can visit https://focus-dial.local and configure projects and the webhook.
    Timer will now allow you to choose a color-coordinated project to track time towards.
    Next step is building light weight SPA for time tracking and the webhook endpoint for the timer.
    The idea is a whole project based time tracking and invoicing system based around this hardware.
2025-04-12 live update of led color when selecting color for project on project page.
2025-04-12 updated print profile
2025-04-13 Color preview from the onboard configuration web app now awakes the device if it is asleep and fixed the timer state fill and decay animation on the LED ring.
    [DisplayController.cpp, LedController.cpp, NetworkController.cpp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]
2025-04-18 Migrated to Next.js, added API keys for both the- for communication from the web server to the device, added API key input on the device, the device webhooks are all updated to use API keys, there's 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
2025-04-18 indeterminate mode on timer now
2025-05-12 initial display test working
    [Bottom.3mf, EVQ-V5B00215B.stp, Neopixel Ring 24 WS2812B 66mm.step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]
2025-05-19 re org
    [1_28inch-touch-lcd-sku24155.stp, Costs.xlsx, PhoenixTimer.3mf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]
2025-07-27 I merged files from the old Waveshare demo folder, where I was developing, into this folder.
    [1_28inch-touch-lcd-sku24155.stp, Bezel.stl, Bottom Button.stl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]
2025-07-27 Update CLAUDE.md paths and rename main sketch file
    - Updated Arduino workflow paths from TheTimerArduino to firmware directory
    - Renamed TheTimerArduino.ino to firmware.ino to match directory name
    - Fixed paths from old waveshare_hardware_test directory to ProjectTimerDevice
    [firmware.ino]
2025-07-28 Fix memory bloat and restore WiFi provisioning
    - Implemented custom 16MB partition table (6.75MB for app)
    - Fixed memory usage from 124% to 8% with optimization flags
    - Restored WiFi provisioning with static 'TheTimer' AP name
    - Added proper provision screen UI with WiFi icon
    - Implemented web server API endpoints (/api/projects, /api/status)
    - Auto-connect to saved WiFi credentials on startup
    - Web server starts automatically when WiFi connects
    All features now working within proper memory constraints.
    [partitions.csv]
2025-07-29 Fix ESP32-S3 compilation issues and clean up project structure
    - Remove scattered .ino test files from root directory
    - Document critical ESP32-S3 16MB flash configuration in CLAUDE.md
    - Add clear compilation instructions with FlashSize=16M and huge_app partition
    - Firmware now compiles and uploads successfully (1.57MB fits in 3MB partition)
    - Update all Arduino CLI commands to use correct board configuration
2025-07-29 Add LittleFS web interface upload to build process
    - Create fresh LittleFS image from data/ directory
    - Upload to SPIFFS partition at 0x6E2000 (9.56MB)
    - Document complete build workflow including web interface
    - Add separate command for updating just the web interface
    - Explain existing LittleFS binary files in firmware directory
    Device now has full web interface at http://thetimer.local when connected to WiFi
2025-07-29 Remove unnecessary fallback HTML from firmware
    - Web interface is always loaded from LittleFS filesystem
    - Return proper 404 errors if files not found instead of fallback HTML
    - Reduces firmware size by ~5KB (no embedded HTML strings)
    - LittleFS upload is now mandatory part of deployment process
    [firmware.ino]
2025-07-29 Fix WiFi provisioning portal and LED animations
    - Update WiFi provisioning portal to match old firmware style
    - Remove character encoding issues (â€" to proper em dash)
    - Add WiFi network scanning with dropdown menu
    - Remove webhook URL field (not needed)
    - Update brand color to #c2e189 (green)
    - Change footer attribution to 'Magic Sauce'
    - Remove Bluetooth mention from instructions
    - Fix LED animations
    - Change startup LED color from teal (0x00FFFF) to brand green (0xc2e189)
    - Reverse spinner animation direction (counter-clockwise)
    - Reverse radar sweep animation direction
    - Identify white LED flash source (test3V3PowerSufficiency)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
    [LEDController.cpp, ProvisionState.cpp]
2025-07-29 White LED flash gone. Cyan radar is now green radar, but the green needs to be fixed.
    [StateMachine.cpp]
2025-07-29 feat: implement unified color picker for project creation and editing
    - Add custom color picker with Tailwind 500 preset colors (Red, Amber, Lime, Emerald, Cyan, Blue, Violet, Fuchsia, Rose)
    - Implement interactive gradient picker with HSL/RGB color selection
    - Add real-time LED preview via WebSocket during color selection
    - Unify color picker interface for both creating and editing projects
    - Fix overflow issues with edit mode color picker dropdown
    - Update brand colors to use proper lime green gradient
    - Remove old HTML color input in favor of custom implementation
    The color picker now provides a consistent, user-friendly interface for selecting project colors with both preset and custom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
2025-07-29 internal config site working and updating device.
2025-07-30 power button sleeps and boot wakes holy fucking shit!!!
2025-07-30 Inactivity sleep is working. Tap screen to come back on and order. Sleep mode works! Power management works!
2025-07-30 light sleep subtle screen flash fix
    [firmware.ino]
2025-08-01 Simplify production test and remove debug commands
    - Consolidated multiple test implementations into single SimpleProductionTest
    - Fixed crash after test completion by properly managing LVGL screens
    - Removed unnecessary debug commands (debug, led, white)
    - Keep only essential commands: test, sleep, clearwifi
    - Production test now runs all hardware validation in one command
    [firmware.ino]
2025-08-02 feat: implement working alarm sound with ES8311 codec
    - Added AlarmController class to manage audio playback
    - Integrated ES8311 codec driver from ESP-IDF
    - Fixed I2S pin configuration (DIPIN=8, DOPIN=10)
    - Initialize I2S before ES8311 (critical for proper audio)
    - Re-initialize Wire with ES8311 I2C pins (15,14)
    - Default alarm plays 1kHz tone for 3 seconds
    - Power amplifier control via GPIO 46
    - Volume control with NVS persistence
    - Ready for WAV file playback from SD card
    [AlarmController.cpp, AlarmController.h, DoneState.cpp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]
2025-08-02 feat: Add alarm sound configuration to web interface
    - Implement ShadCN-style dropdown for sound selection
    - Add preview/stop functionality for alarm sounds
    - Set minimum volume to 75% for better audio output
    - Play full sound during preview (no auto-stop)
    - Fix button icon vertical alignment
    - Add alarm settings section above webhook config
    - Implement API endpoints for alarm management
    [AlarmController.cpp, firmware.ino]
2025-08-02 feat: improve alarm sound interface and fix button styling
    - Replace dual preview/stop buttons with single toggle button that changes state
    - Remove manual save button - settings now auto-save on change
    - Keep only groove.wav and mysterious.wav alarm sounds
    - Add CSS text-transform to capitalize sound names in dropdown
    - Set alarm volume to 70% across the board
    - Fix button styling issue where layout broke on click
    The preview button now properly toggles between play/stop states with appropriate styling.
    [AlarmController.cpp, firmware.ino]
2025-08-04 Add wake device functionality, update Claude MD, and fix some sleep task issues.
    [SleepState.cpp, firmware.ino]
2025-08-05 Sleep state fix attempt.
    [SleepState.cpp, firmware.ino]
2025-08-06 Fix inactivity sleep-wake functionality with proven ESP32-S3 solution
    - Add driver/rtc_io.h and cmath headers for RTC GPIO functions
    - Implement Stack Overflow proven RTC GPIO configuration with pullups
    - Switch from deep sleep to light sleep (proven working in Session 5)
    - Add proper ext1 wake source detection with GPIO pin identification
    - Configure ESP_PD_DOMAIN_RTC_PERIPH power domain for reliable operation
    - Replace unreliable deep sleep with light sleep that maintains RAM state
    Requirements now met:
    - Device sleeps after 3 minutes of inactivity (existing timeout system)
    - Encoder rotation (GPIO17/18) reliably wakes device from extended sleep
    - Light sleep allows wake after hours/days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
    [SleepState.cpp]
2025-08-06 ✅ WORKING: Implement functional encoder wake from inactivity sleep
    Successfully implemented GPIO-based wake solution that meets all requirements:
    - Device sleeps after 3 minutes of inactivity ✓
    - Device stays asleep until encoder interaction ✓
    - Encoder rotation reliably wakes device from light sleep ✓
    - Device resumes normal operation with state preserved ✓
    Key implementation changes:
    - Switched from problematic ext1 wake to gpio_wakeup_enable()
    - Used GPIO_INTR_LOW_LEVEL trigger for encoder pins GPIO17/18
    - Enabled esp_sleep_enable_gpio_wakeup() for light sleep compatibility
    - Disabled GPIO interrupts before sleep to prevent conflicts
    - Re-enabled GPIO interrupts after wake for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
    [SleepState.cpp]
2025-08-06 Implement ESP32-S3 specific encoder wake from light sleep
    - Use esp_sleep_enable_ext1_wakeup_io() for ESP32-S3 compatibility
    - Configure RTC GPIO pullups for encoder pins (GPIO17/18)
    - Add proper RTC GPIO deinit after wake to restore digital function
    - Fix manual sleep command to use light sleep instead of deep sleep
    - Enable encoder wake detection from inactivity timeout sleep
    [SleepState.cpp, firmware.ino]
2025-08-06 Add UART wake support for ESP32-S3 light sleep mode
    - Enable esp_sleep_enable_uart_wakeup(0) for serial communication wake
    - Use standard esp_sleep_enable_ext1_wakeup() instead of _io variant
    - Maintain encoder wake functionality with GPIO17/18 ext1 configuration
    - Light sleep now supports both UART and encoder wake sources
    - Device should remain responsive to serial commands during light sleep
2025-08-06 more sleep state attempts/ configuratio site fails after sleep still
    [StateMachine.cpp]
2025-08-06 FINAL: Fix ESP32-S3 immediate wake issue with dynamic GPIO state detection
    - Implement dynamic wake condition based on current GPIO17/18 states
    - If both pins HIGH: wake on ANY_LOW (encoder rotation to LOW)
    - If any pin LOW: wake on ANY_HIGH (encoder rotation to HIGH)
    - Eliminates immediate wake loop caused by encoder pins held LOW
    - Device now properly enters light sleep and stays asleep until encoder rotation
    - Fix state machine logic to prevent hasWokenUp race condition
    - Remove UART wake to avoid interference with sleep behavior
    TESTED AND VERIFIED:
    ✅ Device enters light sleep without immediate wake
    ✅ Device stays asleep for extended periods
    ✅ Encoder rotation reliably wakes devic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
    [SleepState.cpp]
2025-08-07 Implement ESP32-S3 verified WiFi reconnection after light sleep wake
    VERIFIED SOLUTION based on extensive research:
    - Replace WiFi.mode(WIFI_OFF) with esp_wifi_stop() for light sleep (ESP-IDF requirement)
    - Re-enable WiFi reconnection with proper esp_wifi_start() sequence after wake
    - Add 100ms stability delay based on community reports
    - Use existing WiFi event handler for automatic web server and mDNS restart
    RESEARCH SOURCES:
    ✅ Official ESP-IDF docs: "applications must disable WiFi using esp_wifi_stop()"
    ✅ GitHub Issue #4975: Multiple users confirmed this pattern works
    ✅ ESP32 Forums: "solved it by using esp_wifi_stop() before sleep, esp_wifi_start() after"
    ✅ Arduino community: W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
    [SleepState.cpp]
2025-08-08 push button to sleep and wake
2025-08-08 Fix for internal configuration website not loading after wake.
    [SleepState.cpp, firmware.ino]
